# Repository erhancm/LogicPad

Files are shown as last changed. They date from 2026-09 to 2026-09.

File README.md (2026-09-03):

<p align="center">
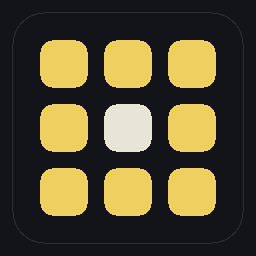
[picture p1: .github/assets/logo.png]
LogicPad
  
</p>

<h1 align="center">LogicPad</h1>

<p align="center">
  <strong>A programmable USB macro pad — and a desktop app that makes it yours.</strong><br>
  Assign macros, build lighting profiles, auto-switch layouts per app, back up your setups, and update firmware — all over USB.
</p>

<p align="center">
  
  
  
  
</p>

<p align="center">
  <a href="#-logicpad-configurator">Configurator</a> ·
  <a href="#-features">Features</a> ·
  <a href="#-hardware">Hardware</a> ·
  <a href="#-quick-start">Quick start</a> ·
  <a href="https://git.erhancm.com/erhan/LogicPad/releases">Download app</a>
</p>

---

## 💻 LogicPad configurator

LogicPad shows up as a standard USB keyboard when you plug it in, so it works without any software. The **Windows, macOS, and Linux** configurator app (built with Tauri 2) gives you a full-screen key editor, YAML profile packs, automatic profile switching based on which app you're using, and **firmware updates over USB**.

<table>
  <tr>
    <td colspan="2" align="center">
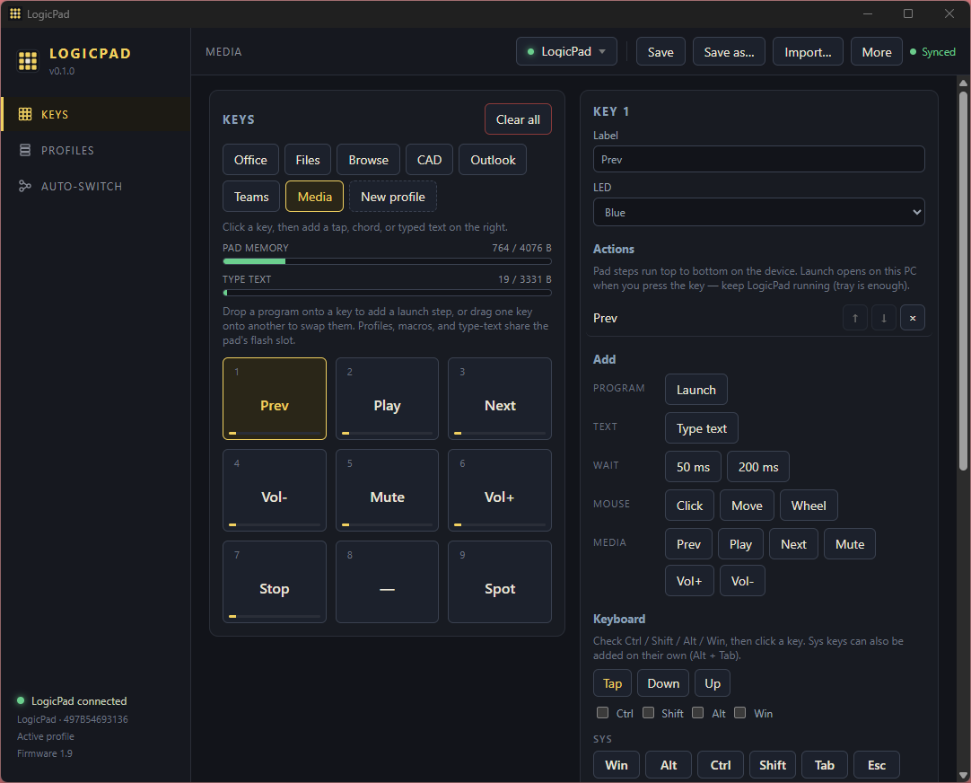
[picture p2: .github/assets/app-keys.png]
LogicPad configurator — Keys tab with 3×3 grid, macro steps, and typed text
      
      <br><sub><b>Keys</b> — macros, chords, typed text, and drag-and-drop PC program launch</sub>
    </td>
  </tr>
  <tr>
    <td width="50%" align="center">
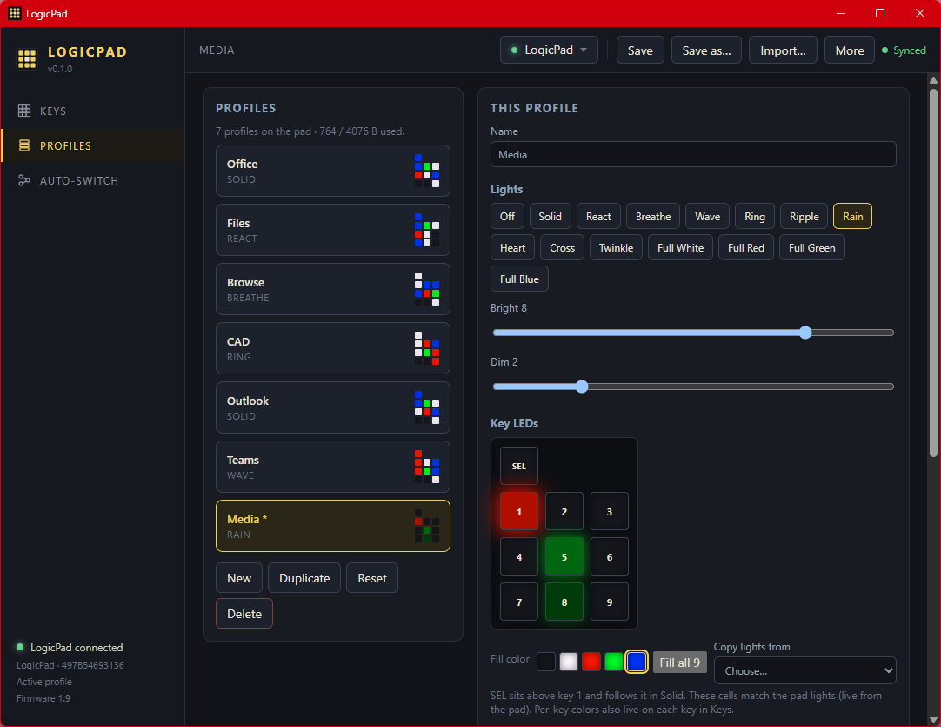
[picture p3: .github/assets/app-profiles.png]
LogicPad configurator — Profiles tab with lighting modes and per-key colours
      
      <br><sub><b>Profiles</b> — wave, ripple, breathe &amp; rain lighting · per-key colours · OLED settings</sub>
    </td>
    <td width="50%" align="center">
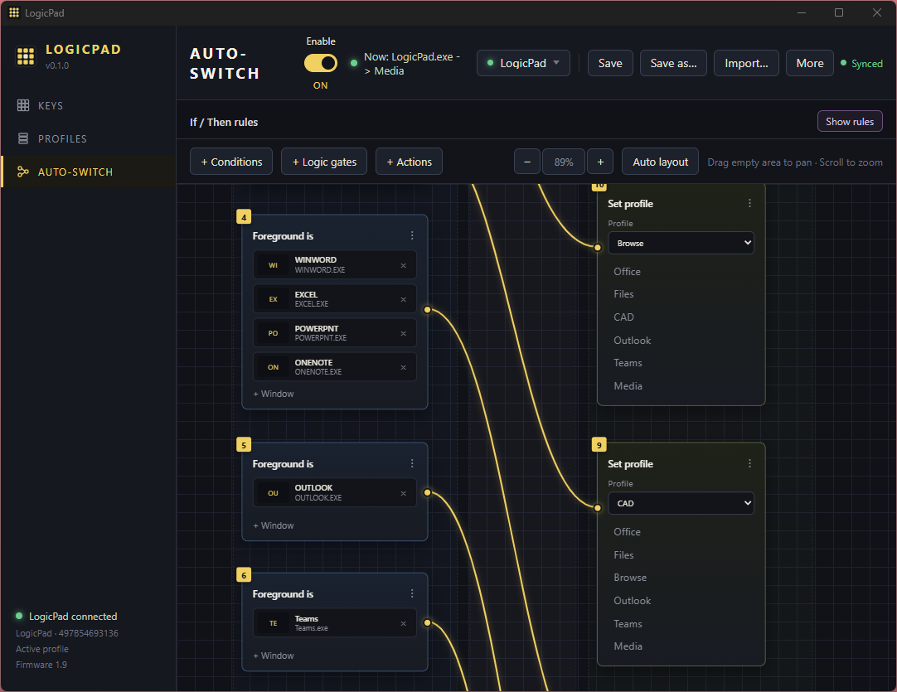
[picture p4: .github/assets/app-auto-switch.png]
LogicPad configurator — Auto-switch node graph
      
      <br><sub><b>Auto-switch</b> — switch profiles when you focus or run specific apps</sub>
    </td>
  </tr>
</table>

### Try it without hardware

The app has a built-in simulated LogicPad so you can try everything without owning the physical board. Note that the software is still a work in progress — some features aren't implemented yet.

### Install the app

Download from **[Releases](https://git.erhancm.com/erhan/LogicPad/releases)**:

| Platform | Download | Install |
|---|---|---|
| **Windows** | `LogicPad_*_x64-setup.exe` | Run the installer |
| **macOS** | `LogicPad_*_x64.dmg` | Open the DMG, drag LogicPad to Applications |
| **Linux** | `LogicPad_*_amd64.AppImage` | `chmod +x LogicPad_*.AppImage && ./LogicPad_*.AppImage` |
| **Linux** | `logicpad-app_*_amd64.deb` | `sudo apt install ./logicpad-app_*_amd64.deb` |
| **All** | `LogicPad-Productivity.yaml` | Import in the app (**Import…**) Example configuration |

**Linux note:** You'll need to install a [udev rule](04%20Software/logicpad-app/README.md#linux-udev) so the app has permission to communicate with the pad over USB. Without it, the app can't detect the device.

**Build from source:** `cd "04 Software/logicpad-app" && npm install && npm run build:app`

**Showcase demo:** [`04 Software/logicpad-app/showcase/`](04%20Software/logicpad-app/showcase/) comes with five pre-built profiles.

**Full app docs:** [`04 Software/logicpad-app/README.md`](04%20Software/logicpad-app/README.md)

---

## 🎯 Features

| | |
|---|---|
| **Keys** | A 3×3 grid of macro keys. Each key can trigger a keyboard shortcut, mouse click, media control or typed string (up to 240 bytes per key). You can also launch a PC program directly from a key. |
| **Profiles** | Create as many profiles as the internal flash allows. Each profile has its own lighting mode (wave, ripple, breathe, rain) or per-key RGB colours. |
| **Auto-switch** | A visual node graph lets you define rules like "when Spotify is focused, switch to the Media profile." Supports foreground-app and running-app checks, AND/OR logic gates.
| **YAML packs** | Export your entire setup — profiles, key mappings, and auto-switch rules — to a single YAML file. Import it later or share it with others. Use **Save as…** / **Import…** in the app. |
| **On-board bootloader** | Every board has a 4 KB USB HID bootloader. After the first flash, you can update firmware straight from the app — no ST-Link or disassembly needed. If something goes wrong, hold **SEL** while plugging in to enter recovery mode. |
| **On-device OLED editor** | Don't have the app? You can configure keys, profiles, and settings entirely from the pad's OLED screen using the selector and the nine keys as a d-pad. |
| **Plug-and-play HID** | LogicPad appears as a standard USB keyboard, mouse, and media device. No custom drivers needed on Windows, macOS, or Linux. |
| **Open hardware** | Full KiCad schematic and PCB layout. |

---

## 🔩 Hardware

<p align="center">
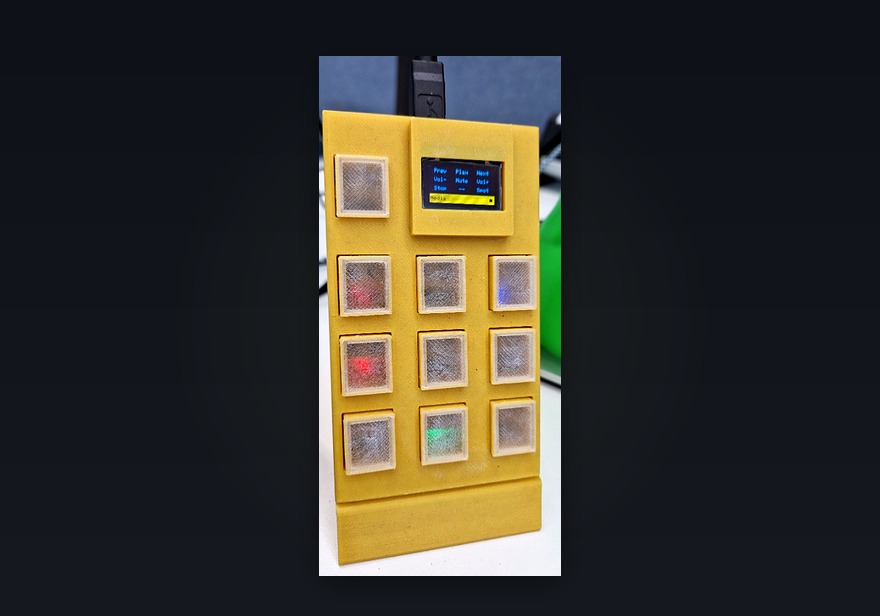
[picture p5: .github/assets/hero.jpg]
LogicPad macro pad — OLED showing Media profile, per-key RGB backlight
  
</p>

<p align="center">
  <em>9 macro keys + selector · 0.96″ OLED · per-key RGB · STM32F103 · 3D-printable enclosure</em>
</p>

| Spec | Detail |
|---|---|
| MCU | STM32F103C8 (ARM Cortex-M3) — 64 KB flash, 20 KB RAM |
| Keys | 9 macro keys + 1 selector button |
| Display | 0.96″ SSD1306 OLED, 128×64 pixels, connected over I²C |
| Lighting | Per-key RGB using 2020-size LEDs |
| USB | Composite HID device — keyboard + mouse + media controls + vendor-specific reports for app communication |
| Flash map | **4 KB** bootloader · **52 KB** application · **8 KB** persistent config store |

Current hardware revision: **V0.2** in [`02 Electronics/V0.2/`](02%20Electronics/V0.2/).

### Firmware updates

Every LogicPad board has a **4 KB USB HID bootloader** baked into flash. Once the board has been programmed for the first time, all future firmware updates happen over a regular USB cable — no ST-Link, no SWD debugger, and no need to open the enclosure.

**Updating firmware:**

1. Build the application firmware with the `Release` CMake preset in [`03 Firmware/Firmware/`](03%20Firmware/Firmware/).
2. Open the configurator app, click **Update firmware**, and select your `LogicPad.bin` file. The app communicates with the bootloader over USB HID and flashes the new image.

**Recovery:** If a firmware update fails or the app won't boot, hold the **SEL** button while plugging in the USB cable. This forces the board into bootloader mode so you can re-flash.

**First-time programming** still requires an ST-Link programmer (one-time only). The factory image `LogicPad_factory.hex` bundles both the bootloader and the application. See [`03 Firmware/bootloader/README.md`](03%20Firmware/bootloader/README.md) for details.

---

## 🚀 Quick start

### Daily use (no app needed)

1. **Plug in USB.** The host OS recognises LogicPad as a standard HID keyboard (plus mouse and media controls if you've configured them). No drivers, no pairing — it just works.

2. **Navigate the OLED menus.** A short press on the **selector** (SEL) button opens the on-device menu. Inside menus, the nine keys double as a d-pad for navigation:

   <table>
     <tr>
       <td width="55%">
         <table>
           <tr><th>Key</th><th>Action</th></tr>
           <tr><td>2</td><td>Up</td></tr>
           <tr><td>8</td><td>Down</td></tr>
           <tr><td>4</td><td>Left</td></tr>
           <tr><td>6</td><td>Right</td></tr>
           <tr><td>5</td><td>OK (select)</td></tr>
         </table>
         <p><strong>Short press SEL</strong> = go back one level. 
       </td>
       <td width="45%" align="center">
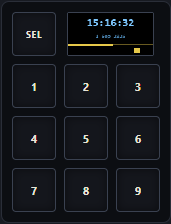
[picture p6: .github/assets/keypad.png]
LogicPad keypad layout
         
       </td>
     </tr>
   </table>

3. **Assign your macros.** Factory boards ship with empty key slots. You can assign macros either from the OLED menu (no PC required) or from the app. The app has more options.

### Build firmware from source

You'll need an ARM GCC toolchain and CMake. Both the bootloader and application firmware use CMake presets.

1. **Build the bootloader** — open [`03 Firmware/bootloader/`](03%20Firmware/bootloader/) and build with the `Release` CMake preset.
2. **Build the application** — open [`03 Firmware/Firmware/`](03%20Firmware/Firmware/) and build with the `Release` CMake preset.
3. **First-time flash** — combine bootloader + app into `LogicPad_factory.hex` and flash it via ST-Link (this is the only time you need ST-Link).
4. **All later updates** — just click **Update firmware** in the configurator app and point it at your new `LogicPad.bin`. The on-board bootloader handles the rest over USB.

---

## 📁 Repository layout

The repo is organised by discipline, numbered so it sorts in a logical order:

| Path | Contents |
|---|---|
| [`01 Documentation/`](01%20Documentation/) | Hardware and protocol docs — MCU pinout, HID report format, OLED menu structure, and C4 architecture diagrams. |
| [`02 Electronics/V0.2/`](02%20Electronics/V0.2/) | KiCad schematic and PCB layout for the current board revision, plus BOM and Gerber files for manufacturing. |
| [`03 Firmware/Firmware/`](03%20Firmware/Firmware/) | Production firmware for the STM32F103. CMake-based build with ARM GCC. Handles USB HID, key scanning, OLED display, RGB lighting, and config storage. |
| [`03 Firmware/bootloader/`](03%20Firmware/bootloader/) | On-board USB HID bootloader. Occupies the first 4 KB of flash and allows firmware updates over USB without a debugger. |
| [`04 Software/logicpad-app/`](04%20Software/logicpad-app/) | Desktop configurator app — Tauri 2 (Rust + web frontend). Handles key editing, profile management, auto-switch rules, YAML import/export, and firmware updates. |
| [`05 Hardware/`](05%20Hardware/) | 3D-printable enclosure — STEP files for the case and button caps. |
| [`.github/assets/`](.github/assets/) | Images used in this README. |

---

## 📖 Documentation

- [Pinout](01%20Documentation/Pinout.md) — MCU pin assignments, key matrix wiring, OLED connections, and RGB data lines
- [HID protocol](01%20Documentation/HID_PROTOCOL.md) — USB HID report format and vendor-specific commands used by the configurator app
- [OLED UI](01%20Documentation/OLED_UI.md) — on-device menu structure and navigation flow
- [C4 architecture](01%20Documentation/C4_MODEL.md) — high-level system overview in C4 model notation

---

## 🤝 Contributing

Contributions are welcome — whether it's a bug report, a feature request, or a pull request. If you're planning a larger change, it's worth opening an issue first to discuss the approach. By contributing, you agree that your contributions will be licensed under [Apache 2.0](LICENSE).

---

## 🐛 Known issues

| Issue | Type | Status | Notes |
|---|---|---|---|
| Sometimes you can't pan across the node editor when clicking on an empty area and dragging the mouse | Software | Open | Needs more investigation |
| OLED flicker or banding when taking pictures with camera| Software | Open | To do with refresh rate |
| Standby Clock setting is not persistant | Firmware | Open | When powering the unit off and on, the standby clock is reset to the default setting |
| Not all standby clock styles work | Software + Firmware | Open | Needs more investigation |
| LEDs can't reach full brightness in custom lighting modes | Hardware | Open | The LEDs are scanned one key at a time (1/9 duty cycle), so each LED is only actually on for a fraction of the time — the rest just looks lit because of persistence of vision. The STM32F103's GPIO pins can't source enough current to drive all 27 LEDs (9 keys × 3 colours) at once, so the per-LED brightness is capped by the scan rate. |

---

## 📝 To-do

| Feature | Type | Status | Notes |
|---|---|---|---|
| Custom scripting assignable to each button | Software | Planned | Python/Lua scripts — TBD |
| Mouse and keyboard recording | Software | Planned | Record input sequences and replay them from a key |
| OCR-based automation | Software | Planned | Use image recognition to perform actions based on what's on screen |
| Long press functions | Software + Firmware | Planned | Different actions for short vs. long key presses |
| Profile hotkeys | Firmware | Planned | Assign a key to cycle through or jump to specific profiles instead of going through the on-board menu (temporarily override auto-switch condition) |

### Hardware V0.3

| Feature | Status | Notes |
|---|---|---|
| Upgrade MCU to STM32F4 or RP2040 | Planned | More flash and RAM for larger configs, scripting support, and faster USB |
| USB-C connector | Planned | Replace the current Micro-USB with USB-C for better durability and reversibility |
| Hot-swap key sockets | Planned | Swap switches without soldering |
| Per-key addressable LEDs (WS2812B) | Planned | Remove the 1/9 scanning limitation and allow full brightness on all keys simultaneously |
| Larger OLED display | Planned | Upgrade from 0.96″ to 1.3″ for more readable menus and more info on screen |
| Rotary encoder | Planned | Add a clickable rotary encoder for volume control, scrolling, or menu navigation |
| Slider potentiometer | Planned | Linear slider for volume, brightness, or other continuous control |
| External flash storage | Planned | Dedicated flash chip or SD card slot — TBD. Would allow storing more profiles, macros, and recorded scripts on-device |
| Temperature and humidity sensor | Planned | Environmental sensor for ambient readings displayed on the OLED or used in automation rules. Including support for logging |

---

## 📄 License

This project is licensed under the [Apache License 2.0](LICENSE).

The third-party libraries bundled in `03 Firmware/Firmware/Drivers/` — namely the STM32 HAL, CMSIS, and ST's USB device library — are not covered by this license. They remain under their respective upstream licenses from STMicroelectronics and ARM.

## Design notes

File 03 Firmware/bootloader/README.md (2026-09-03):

# LogicPad HID bootloader

4 KB USB HID updater at `0x08000000`. The STM32F103C8 ROM loader has no USB DFU.

## Build

Needs `arm-none-eabi-gcc` on PATH (STM32CubeCLT is fine).

```
cd "03 Firmware/bootloader"
cmake --preset Release
cmake --build --preset Release
```

Produces `build/Release/bootloader.bin` (must be ≤ 4096 bytes).

Then build the app with CMake preset `Release` in `03 Firmware/Firmware/`. That writes `LogicPad.bin` (updater image) and, if the bootloader binary exists, `LogicPad_factory.hex` (first ST-Link flash).

## First flash (ST-Link, once)

Program `LogicPad_factory.hex`. After that, use the Tauri app **Update firmware** with `LogicPad.bin` only.

## Recovery

Hold SEL while plugging USB. Device enumerates as **LogicPad Boot** (VID `0x0483`, PID `0x5751`). OLED shows **BOOT** / **USB FLASH**.

In-app **Update firmware** resets into this loader (software-reset stay + SRAM magic). The OLED boot screens and that stay logic only update when you ST-Link `LogicPad_factory.hex`.

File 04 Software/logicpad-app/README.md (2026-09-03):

# LogicPad configurator

Optional Tauri 2 desktop app. The pad works as a USB HID keyboard without it.

Talks **vendor HID report 4** only (usage page `0xFF00`), so the host keeps reports 1–3 for typing. USB IDs: ST test VID/PID `1155` / `22352` (application) and `22353` (`0x5751`, bootloader) until custom IDs are assigned.

Licensed under [Apache 2.0](../LICENSE).

## Daily use (Windows)

**Install from a [Gitea Release](https://git.erhancm.com/erhan/LogicPad/releases)** — pick the installer for your OS (Windows `.exe`, macOS `.dmg`, Linux `.AppImage` or `.deb`), then start **LogicPad**.

Or build locally:

```
cd "04 Software/logicpad-app"
npm install
node generate-icons.mjs
npm run build:app
```

Or double-click `Build LogicPad.bat` in that folder. That installs to `%LOCALAPPDATA%\LogicPad\` (current user, no admin) and writes:

- `src-tauri/target/release/LogicPad.exe` — the raw program
- `src-tauri/target/release/bundle/nsis/LogicPad_0.1.0_x64-setup.exe` — installer

WebView2 is already on Windows 10/11. Rebuild the same way after app code changes.

## Develop

Needs Node 20+ and [Rust](https://rustup.rs/) (stable). On Windows, MSVC build tools. Cargo must be on `PATH` (`%USERPROFILE%\.cargo\bin`).

```
cd "04 Software/logicpad-app"
npm install
npm run tauri dev
```

Connect with a pad plugged in, or use the **Simulated LogicPad** to draft a setup on this PC. **Save as…** writes a YAML pack; **Import…** applies that file onto whichever pad is selected in **Pad**. One pad is selected automatically; two or more keep the last one you used. Edit the 3×3 keys and macros on **Keys**. **Profiles** is name, lighting, key LEDs, duplicate/reset, and OLED Screen (contrast / flip / sleep). **New** / **Duplicate** / **Delete** add or remove a profile (until the pad’s flash slot is full). **Save** writes flash on the device (or the local simulated store). **Update firmware** takes the app `LogicPad.bin` (not the factory hex) and programs the selected USB pad.

Drop an `.exe` or shortcut onto a key to launch it from this PC (stored locally, not on the pad). Key labels are 12 characters on current firmware (OLED wraps to two lines past 10). The **Type text** box is what the pad types over USB; a live bar shows pad flash (profiles + macros + text share one slot) and 240 B max per key. Flash firmware that includes `GET_TEXT` / `SET_TEXT` (`0x0F` / `0x10`) for strings longer than 12 characters, and `GET_TITLE` / `SET_TITLE` (`0x13` / `0x14`) for 12-character key names. Packed-store firmware uses magic `LPAI` and migrates `LPAH` config on boot.

**Launch program** on a key is stored on this PC (not on the pad). Pressing that key opens the file while this app is running. Flash firmware that includes `KEY_EVENT` (`0x0D`).

**Auto-switch** on the **Auto-switch** tab switches pad profiles when you focus an app. Use the compact rules list or open the **graph** editor for AND/OR, running checks, foreground/not-focused logic, and a default fallback (for example a Media profile when no rule matches). Rules are stored locally (`profile-rules.json`), not on the pad. Enable auto-switch in the app; it can start with Windows when launch mappings or rules exist. Firmware that does not mark the store dirty on `SET_ACTIVE` avoids an OLED save prompt on every Alt-Tab.

Home/sleep on the pad shows the **active profile** while you are using Windows. The clock comes back if USB drops, the session is locked, or you log off. That lock/logoff switch needs this tray app (and firmware with `SET_HOST` `0x15`).

## Linux udev

Not a custom driver. One rule so hidapi can open hidraw without root:

```
# /etc/udev/rules.d/99-logicpad.rules
KERNEL=="hidraw*", ATTRS{idVendor}=="0483", ATTRS{idProduct}=="5750", MODE="0666", TAG+="uaccess"
KERNEL=="hidraw*", ATTRS{idVendor}=="0483", ATTRS{idProduct}=="5751", MODE="0666", TAG+="uaccess"
```

Then `sudo udevadm control --reload-rules && sudo udevadm trigger`.

## Protocol

See [`01 Documentation/HID_PROTOCOL.md`](../../01%20Documentation/HID_PROTOCOL.md). Key payloads are the first 60 bytes of `lp_key_t` (up to 12 actions).

## Releases

Publish with [`scripts/Publish-Gitea-Release.ps1`](../../scripts/Publish-Gitea-Release.ps1) (Windows only) or push a **`v*`** tag to trigger the cross-platform [`.gitea/workflows/release.yml`](../../.gitea/workflows/release.yml).

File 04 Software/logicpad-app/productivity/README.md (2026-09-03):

# Productivity profile pack

Example YAML setup: **Office**, **Files**, **Browse**, **CAD**, **Outlook**, **Teams**, and a **Media** fallback when no productivity app is focused.

## Apply to a connected pad

From PowerShell (LogicPad installed):

```powershell
& "04 Software\logicpad-app\productivity\Apply-Productivity.ps1"
```

LogicPad restarts, queues the setup, writes to USB flash when the pad connects, and opens the **Auto-switch** tab.

## Import manually

**Import…** in the companion app with `LogicPad-Productivity.yaml`.

## Regenerate after editing sources

```powershell
cd "04 Software/logicpad-app"
npx tsx productivity/export-yaml.ts
```

Profile and auto-switch definitions live in `src/productivity.ts` and `src/productivityGraph.ts`.

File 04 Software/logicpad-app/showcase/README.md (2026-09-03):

# LogicPad Showcase Demo

Advertising-ready configuration: **five profiles**, rich macros, PC program launches, and a **complex auto-switch graph** (multi-app OR, AND + running, running-only, else-restore).

## Apply to your connected pad

From PowerShell:

```powershell
& "04 Software\logicpad-app\showcase\Apply-Showcase.ps1"
```

LogicPad restarts, detects the flag, writes the demo to USB flash, and opens the **Auto-switch** tab.

## Profiles

| Profile | Lights | Highlights |
|---|---|---|
| **Create** | Wave / blue keys | Copy, paste, save, typed snippet, launch Cursor |
| **Stream** | Ripple / red | OBS scene hotkeys, media volume, mouse click, launch OBS |
| **Meet** | Solid / green | Mute, camera, share, leave, launch Teams |
| **Browse** | Breathe / white | Tabs, back/forward, reload, typed URL |
| **Play** | Rain / blue | Media transport, multi-step macro |

## Auto-switch graph

1. **Create** — foreground `Cursor.exe`, `Code.exe`, or `Figma.exe`
2. **Stream** — foreground `obs64.exe` **and** `Discord.exe` running
3. **Meet** — foreground `Teams.exe` or `Zoom.exe`
4. **Browse** — foreground Chrome, Edge, or Firefox
5. **Play** — `Spotify.exe` running anywhere
6. **Else** — restore previous profile

## Share as YAML

Import `LogicPad-Showcase.yaml` via **Import…** in LogicPad (includes full auto-switch graph).

Regenerate after editing `src/showcase.ts`:

```powershell
cd "04 Software\logicpad-app"
npx tsx showcase/export-yaml.ts
```

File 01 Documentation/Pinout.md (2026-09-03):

# LogicPad Pinout

This is the definitive pin-mapping reference for the LogicPad hardware. Firmware must match this document.

**MCU:** STM32F103C8 (48-pin LQFP, 72 MHz, USB FS)
**USB:** Type-B connector, using the STM32's built-in USB FS peripheral. Standard OS HID drivers — no custom kernel driver needed.
**OLED:** 0.96-inch SSD1306, 128 x 64 pixels, connected over I2C1.

---

## Key Matrix

The 3 x 3 key grid plus the selector button are scanned as a matrix. The MCU drives columns low one at a time and reads the rows to detect which key is pressed.

**Scanning method:** Column drive, row read. Columns sit idle-high; the firmware pulls one column low per scan step and reads the row pins. A pressed key shows as low on its row when its column is driven low.

| Net Name | MCU Pin | Direction | Notes |
|---|---|---|---|
| Column_0 | PB5 | Output | Idle high; driven low to scan |
| Column_1 | PB4 | Output | Available as GPIO because SWJ is set to NOJTAG mode |
| Column_2 | PB3 | Output | Available as GPIO because SWJ is set to NOJTAG mode |
| Row_0 | PB12 | Input, pull-up | Top row of the key grid |
| Row_1 | PB13 | Input, pull-up | Middle row |
| Row_2 | PB14 | Input, pull-up | Bottom row |
| Selector | PB15 | Input, pull-up | Standalone button below the grid. Short press = menu/back, long press (500 ms) = home. Not a 10th macro key. |

### Key Index Map

Keys are indexed in row-major order (left to right, top to bottom):

```
[0] [1] [2]      row 0
[3] [4] [5]      row 1
[6] [7] [8]      row 2
      [SEL]       selector button (below the grid, centered)
```

> **Note:** Older test firmware used the opposite scanning direction (row drive, column read). Do not use that polarity — the current production firmware uses column drive / row read as described above.

---

## OLED Display (I2C1)

The SSD1306 OLED communicates over I2C1 at 400 kHz (fast mode).

| Net Name | MCU Pin  | I2C Function |
|---|---|---|
| SCL | PB6 | I2C1 clock |
| SDA | PB7 | I2C1 data |

**I2C address:** `0x78` (8-bit HAL address, which is `0x3C` in 7-bit notation).

---

## Per-Key RGB LEDs

Each of the 9 keys and the selector button has its own RGB LED. The LEDs are driven by a software PWM multiplexer running on TIM2 at 16 kHz (about 111 Hz refresh per key with 16 PWM steps).

### Anode (High-Side) Switches — PA0 through PA8

Each key's LED anode is switched through a **BSS84 P-channel MOSFET**. The GPIO pins on PA0 through PA8 control these switches:

| Net Name | MCU Pin | Key Index | Notes |
|---|---|---|---|
| C0R0 | PA0 | 0 | Top-left key |
| C0R1 | PA1 | 1 | Top-center key |
| C0R2 | PA2 | 2 | Top-right key |
| C1R0 | PA3 | 3 | Middle-left key |
| C1R1 | PA4 | 4 | Middle-center key |
| C1R2 | PA5 | 5 | Middle-right key |
| C2R0 | PA6 | 6 | Bottom-left key |
| C2R1 | PA7 | 7 | Bottom-center key |
| C2R2 | PA8 | 8 | Bottom-right key |
| CtrlLed  | PA9 | SEL | Selector RGB LED (10th pixel, not a 10th macro key) |

**Polarity:** GPIO **low = LED on**, GPIO **high = LED off** (P-FET high-side switch).

> **Important:** The net names (C0R0, C0R1, C0R2, ...) walk down each column on the MCU port, which is the transpose of the physical key grid. The firmware accounts for this — key index 0 maps to C0R0 (PA0), key index 1 maps to C0R1 (PA1), and so on in row-major order.

### Color Sink (Low-Side) Switches — PB8, PB9, PB10

The red, green, and blue color channels share common sink lines. Each channel is switched through a **2N7002 N-channel MOSFET**:

| Net Name | MCU Pin | Color  | Polarity |
|---|---|---|---|
| R_Ctrl | PB8 | Red | GPIO **high = on**, low = off |
| G_Ctrl | PB9 | Green  | GPIO **high = on**, low = off |
| B_Ctrl | PB10 | Blue | GPIO **high = on**, low = off |

White is achieved by turning on all three color channels simultaneously.

---

## USB

The LogicPad connects to the host via a **USB Type-B** connector wired to the STM32F103's built-in USB FS peripheral. It presents as a standard HID composite device (keyboard, mouse, media keys, and vendor-specific reports). The host OS uses its inbox HID drivers — no custom kernel driver is required.

---

## Pin Usage Summary

| Port | Pins Used | Function |
|---|---|---|
| PA0  | PA0 - PA8 | LED anode switches (9 keys) |
| PA9  | PA9 | Selector LED anode switch |
| PA11 | PA12 | USB D- / D+ (USB FS peripheral) |
| PB3  | PB3 - PB5 | Key matrix columns (outputs) |
| PB6  | PB7 | I2C1 SCL / SDA (OLED) |
| PB8  | PB8 - PB10  | LED color sinks (R, G, B) |
| PB12 | PB12 - PB14 | Key matrix rows (inputs, pull-up) |
| PB15 | PB15 | Selector button (input, pull-up) |

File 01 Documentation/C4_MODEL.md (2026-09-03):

# LogicPad C4 Model

This document describes the LogicPad system using the [C4 model](https://c4model.com/) — four levels of increasing detail, from the big picture down to individual data structures.

LogicPad is a USB HID macro pad. It presents itself as a standard keyboard, mouse, and media device — **there is no custom kernel driver**. The host OS handles reports 1–3 with its inbox HID stack. Report 4 (vendor) is opened in userspace by the optional desktop app via hidapi.

**Source files:** `README.md`, `HID_PROTOCOL.md`, `Pinout.md`, `OLED_UI.md`, `03 Firmware/`, `04 Software/logicpad-app/`.

| Level | What it shows |
|---|---|
| 1 — Context | People and external systems around LogicPad |
| 2 — Containers | Deployable units: firmware images, OS HID drivers, the Tauri app, config files |
| 3 — Components | Modules inside each container: firmware C modules, Rust backend, React UI, USB stack |
| 4 — Code | Flash memory map, HID report layout, vendor command table |

---

## Level 1 — System Context

The macro pad works as a standalone USB HID device — just plug it in and type. The OLED screen and physical keys let the operator configure macros directly on the device. The desktop configurator app is entirely optional; it provides a richer editing experience, profile management, firmware updates, and automatic profile switching based on the focused application.

Factory programming (first flash or brick recovery) uses an ST-Link debugger over SWD. After that, all firmware updates go through the built-in HID bootloader — no special tools needed.

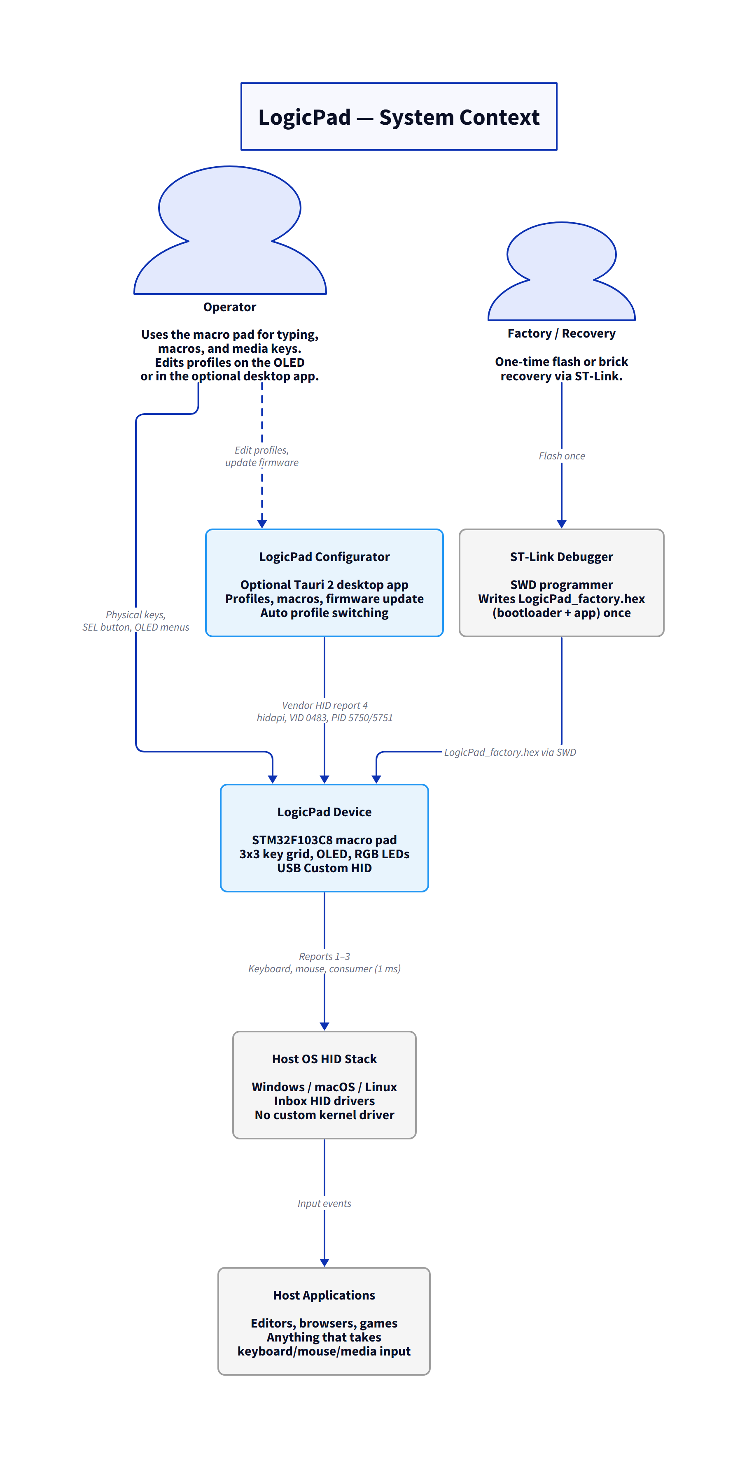
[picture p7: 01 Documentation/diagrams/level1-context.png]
Level 1 — System Context


---

## Level 2 — Containers

The device exposes a single USB Custom HID interface. The OS automatically claims reports 1–3 (keyboard, mouse, consumer) through its standard class drivers. The desktop app opens only the vendor collection (usage page `0xFF00`), so normal typing continues uninterrupted while the app is connected.

On the host side, the Tauri app bundles a React frontend with a Rust backend. The Rust side owns the hidapi connection and handles all USB communication. The app stores host-side configuration (launch mappings and profile switch rules) in JSON files — these live on the PC, not in the pad's flash.

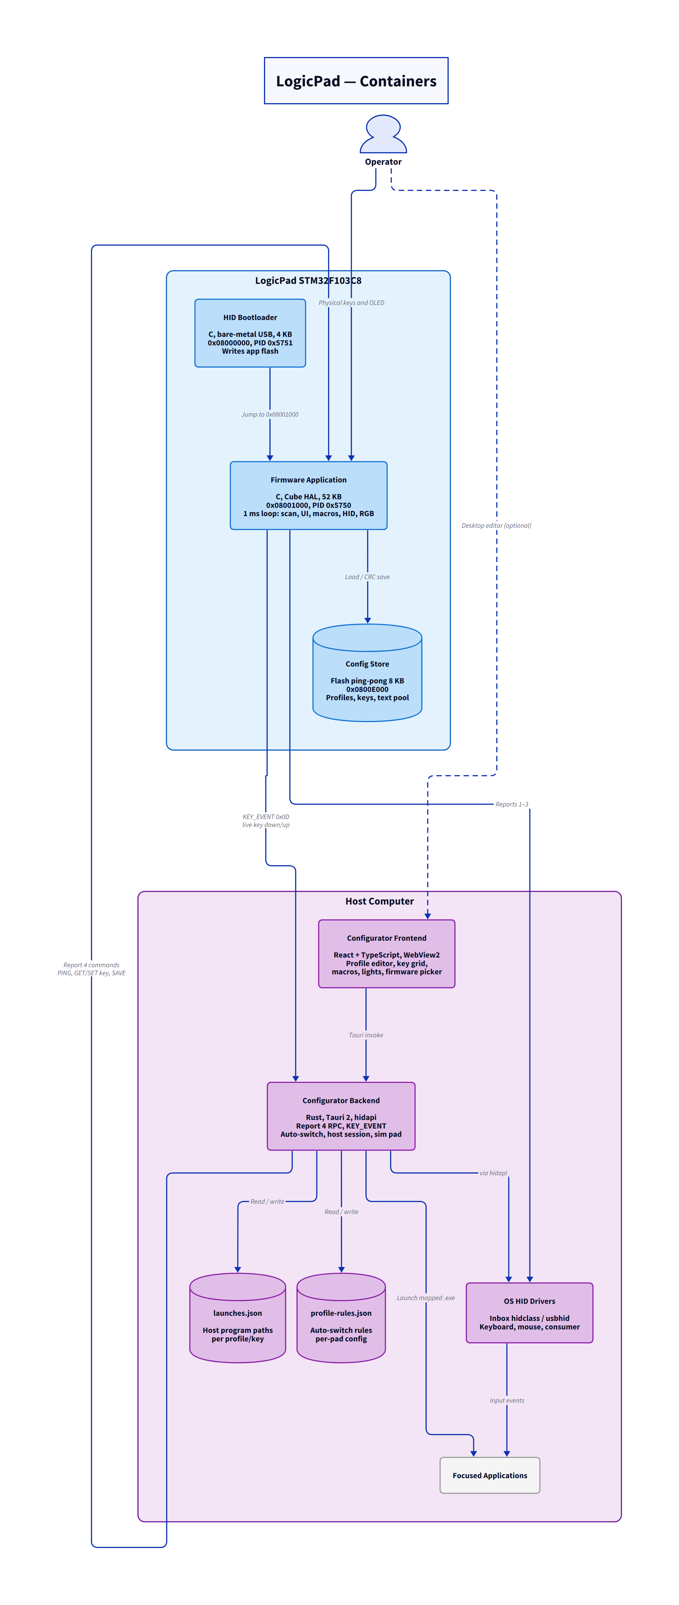
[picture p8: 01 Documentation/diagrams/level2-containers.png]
Level 2 — Containers


**Linux note:** hidapi needs access to `/dev/hidraw`. The udev rule in the app README grants this permission — it is not a driver.

---

## Level 3 — Firmware Application

The firmware runs a catch-up tick loop in `main.c`. Each iteration processes all elapsed milliseconds since the last pass, calling `ui_tick()` for each one (which includes keypad scanning). After the tick loop, `hid_tick()` and `macro_tick()` run once. OLED drawing is deferred to when the macro engine is idle, since the I2C transfer to the SSD1306 display takes ~25 ms and would otherwise stall HID reporting.

USB IN/OUT is interrupt-driven through ST's device library. The bootloader has its own separate bare-metal USB stack (`bootloader/usb.c`) and is not shown here.

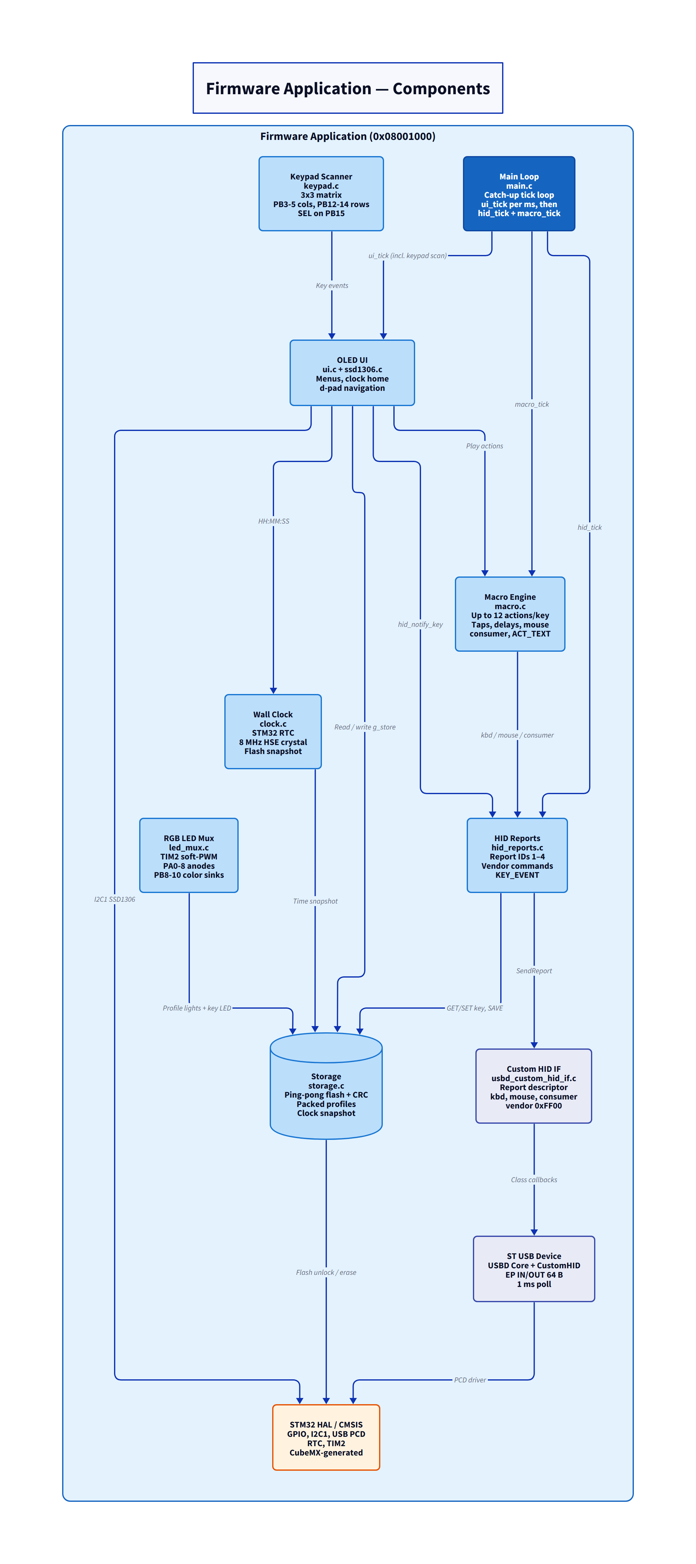
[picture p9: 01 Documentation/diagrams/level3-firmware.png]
Level 3 — Firmware Application


**Related docs:** [Pinout.md](Pinout.md) for hardware pins, [OLED_UI.md](OLED_UI.md) for screen layouts.

---

## Level 3 — Desktop Configurator

The desktop app is a Tauri 2 application with a React frontend and a Rust backend. The frontend never opens HID directly — all USB communication goes through the Rust side, which owns the hidapi connection on a dedicated worker thread.

The backend has grown beyond simple pad editing. It now handles automatic profile switching based on the focused Windows application, host session detection (lock/unlock), live window previews, and an in-memory simulated pad for testing without hardware.

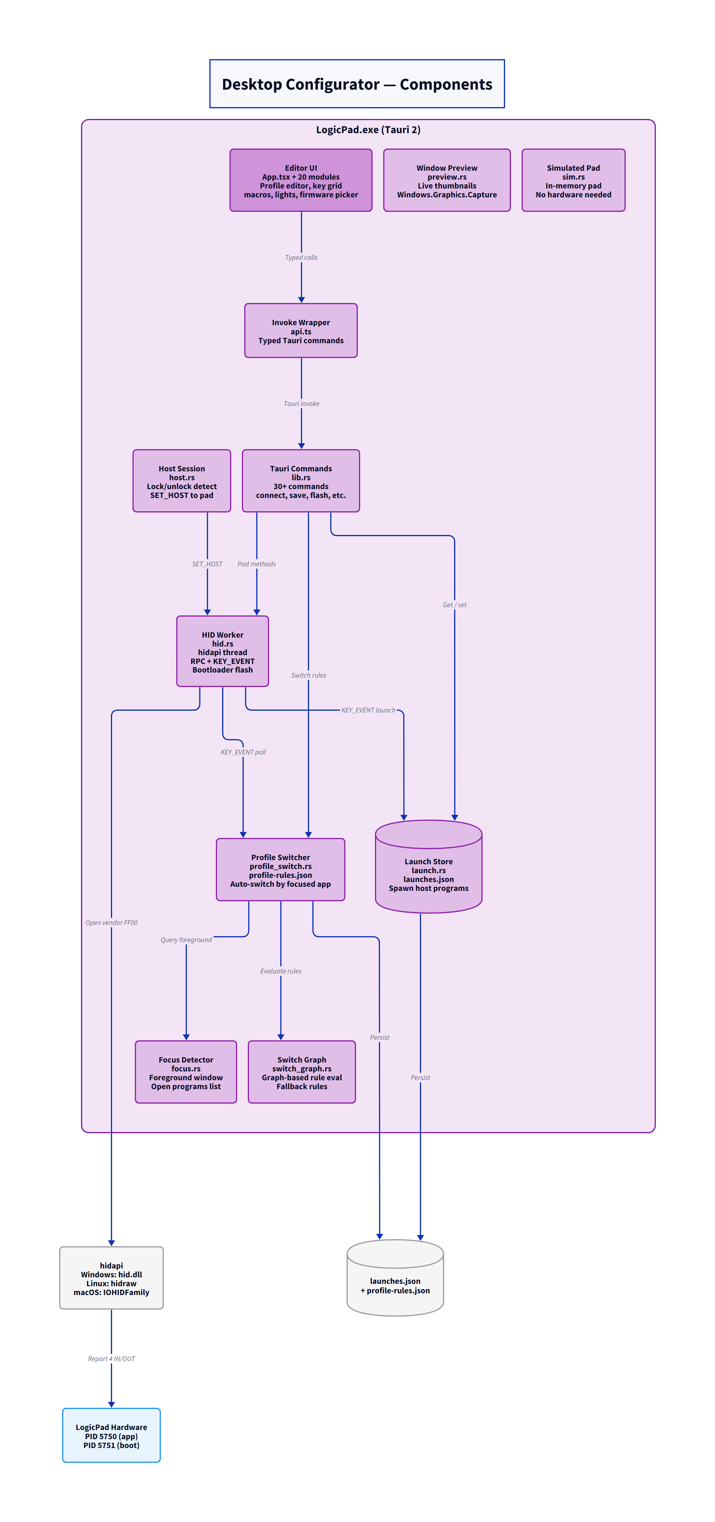
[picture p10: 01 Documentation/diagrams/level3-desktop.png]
Level 3 — Desktop Configurator


---

## Level 3 — USB / HID Stack (No Custom Driver)

This diagram shows the USB path as a stack of layers, from the application protocol down to the wire and back up on the host side. The bootloader does **not** use the ST USB library — it drives the same USB FS peripheral directly in `bootloader/usb.c`.

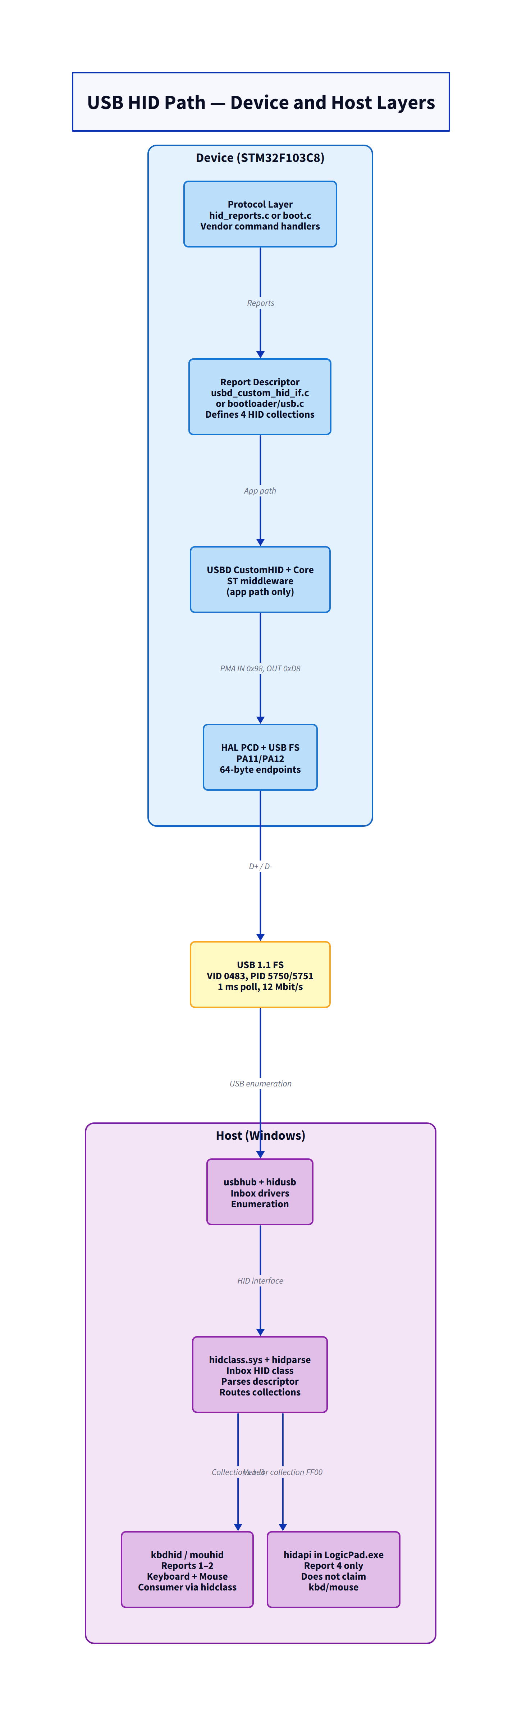
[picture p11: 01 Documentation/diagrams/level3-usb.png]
Level 3 — USB HID Stack


| Host OS | Reports 1–3 (keyboard/mouse/consumer) | Report 4 (vendor) |
|---|---|---|
| Windows | hidclass.sys + kbdhid/mouhid | hidapi via hid.dll (skips usage pages 0x01, 0x02, 0x0C) |
| macOS | IOHIDFamily | hidapi via IOHIDManager |
| Linux | usbhid + evdev | hidraw; requires udev rule `99-logicpad.rules` for unprivileged access |

---

## Level 4 — Code: Flash Map and HID Reports

**Chip:** STM32F103C8 — 64 KB flash, 20 KB SRAM. The built-in ROM bootloader only supports USART, so field firmware updates use the 4 KB HID bootloader instead.

### Flash Memory Map

| Region | Address | Size | Contents |
|---|---|---|---|
| HID Bootloader | `0x08000000` | 4 KB | Included in `LogicPad_factory.hex` only. Bare-metal USB stack. |
| Application | `0x08001000` | 52 KB | `LogicPad.bin` (also bundled in factory hex). Main firmware. |
| Config Store | `0x0800E000` | 8 KB | Ping-pong slots with CRC. Packed profiles, keys, text pool, clock snapshot. |
| SRAM Magic | `0x20004FFC` | 4 bytes | Write `LPBL` here before reset to stay in bootloader (used by ENTER_BOOTLOADER). |

### HID Reports

| Report ID | Size (bytes) | Direction | Handled By | Purpose |
|---|---|---|---|---|
| 1 | 9 | IN | OS | Keyboard: modifier byte + 6-key rollover |
| 2 | 5 | IN | OS | Mouse: buttons, X, Y, wheel |
| 3 | 3 | IN | OS | Consumer control: 16-bit usage (volume, media, etc.) |
| 4 | 64 | IN/OUT | App / Bootloader | Vendor commands (see HID_PROTOCOL.md) |

### Vendor Commands (Application)

The full command table is documented in `HID_PROTOCOL.md`. Key commands include:

| Cmd | Name | Description |
|-----|---|---|
| 0x01 | PING | Returns protocol version (major, minor) |
| 0x02 | GET_META | Active profile, dirty flag, OLED settings, store usage |
| 0x03 | GET_KEY | Read key config (label, LED, actions) for a profile/key |
| 0x04 | SET_KEY | Write key config |
| 0x05 | SET_ACTIVE | Switch live profile (does not mark flash dirty) |
| 0x06 | SAVE | Persist current config to flash with CRC |
| 0x0C | ENTER_BOOTLOADER | Ack, show OLED message, reset into HID bootloader |
| 0x0D | KEY_EVENT | Unsolicited: live key down/up notification |
| 0x0E | SET_TIME | Sync wall clock from host |
| 0x0F–0x10 | GET/SET_TEXT | Type-text pool read/write (chunked) |
| 0x11–0x12 | ADD/DEL_PROFILE | Add or delete profiles (up to 255) |
| 0x13–0x14 | GET/SET_TITLE | 12-character display title per key |
| 0x15 | SET_HOST | Notify pad of host session state (locked/unlocked) |
| 0x16 | SET_SCREEN | OLED contrast, flip, sleep timeout, clock style |
| 0x17 | GET_LEDS | Live RGB snapshot for app-side LED preview |
| 0x18 | PREVIEW_CLOCK | Show/hide clock preview on OLED |

**Bootloader commands:** `0x40` BL_START, `0x41` BL_DATA, `0x42` BL_FINISH, `0x43` BL_ABORT.

### Store Schema

Defined in `03 Firmware/Firmware/Core/Inc/storage.h`. The current packed format uses magic `LPAI` (`0x4C504149`). The bootloader migrates legacy `LPAH` (`0x4C504148`, fixed 4-profile) stores into the packed layout on first boot. Up to 255 profiles, 9 keys per profile, 12 actions per key, 240 bytes of type-text per key.

---

## Runtime Paths

These trace common operations through the code, showing which components are involved at each step.

### Typing a key (standalone, no desktop app)

1. `main.c` tick loop calls `ui_tick()`
2. `keypad.c` scans the 3x3 matrix, detects a key press (with debounce)
3. `ui.c` receives the event, looks up the active profile's key config
4. `macro.c` plays the key's action sequence (HID taps, delays, mouse moves, consumer keys, typed text)
5. `hid_reports.c` sends reports 1–3 via `usbd_custom_hid_if.c` → ST USB library → USB FS peripheral
6. Host OS HID stack delivers input to the focused application

### Typing a key (desktop app running, with launch mapping)

Same HID path as above (reports 1–3 still go to the OS), **plus:**

1. `hid_reports.c` sends an unsolicited `KEY_EVENT` (0x0D) over report 4
2. `hid.rs` worker thread receives it, dispatches to the registered callback
3. `launch.rs` checks if this profile/key has a mapped host program — if so, spawns it
4. `profile_switch.rs` also receives the event and can trigger auto-switch logic

### Auto profile switching (desktop app)

1. `profile_switch.rs` polls the focused Windows application via `focus.rs`
2. `switch_graph.rs` evaluates the rule graph against the focused program's executable name
3. If a rule matches and the profile differs from the current one, sends `SET_ACTIVE` to the pad
4. Debounce timer (400 ms) prevents rapid switching during alt-tab

### Host session detection (desktop app)

1. `host.rs` monitors Windows session events (lock, unlock, fast-user-switch, logoff)
2. When the session state changes, sends `SET_HOST` (0x15) to the pad
3. The pad uses this to decide whether to show the clock or profile name on the home screen, and when to enter sleep

### Saving from the desktop app

1. React UI calls `save_store` via the invoke wrapper
2. `lib.rs` forwards to `hid.rs` which sends `CMD_SAVE` (0x06) over report 4
3. `storage.c` on the pad writes the current config to flash with a CRC checksum

### Firmware update

1. Desktop app sends `ENTER_BOOTLOADER` (0x0C) — the pad acks, shows "FLASH / BOOT MODE" on the OLED, then resets
2. SRAM magic `LPBL` tells the bootloader to stay in update mode
3. Pad re-enumerates as PID `0x5751` (LogicPad Boot)
4. App sends `BL_START` (size + CRC), then `BL_DATA` chunks, then `BL_FINISH`
5. Bootloader verifies CRC and vector table, then jumps to `0x08001000`
6. **Recovery:** hold SEL while plugging in USB to force bootloader mode

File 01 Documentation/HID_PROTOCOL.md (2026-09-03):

# LogicPad HID Protocol

This document describes the USB HID protocol used by LogicPad — a macro pad that presents itself as a standard keyboard, mouse, and media device over a single Custom HID interface. The host OS handles reports 1–3 with its inbox class drivers; no custom kernel driver is needed. Report 4 (vendor) is ignored by the OS and opened in userspace by the optional Tauri desktop app via hidapi.

**Source files:** `03 Firmware/Firmware/Core/Inc/hid_reports.h`, `03 Firmware/Firmware/Core/Src/hid_reports.c`, `03 Firmware/Firmware/Core/Inc/storage.h`, `03 Firmware/bootloader/boot.c`, `04 Software/logicpad-app/src-tauri/src/hid.rs`.

---

## Report IDs

| ID | Size (incl. ID) | Direction | Purpose |
|----|---|---|---|
| 1 | 9 | IN | Keyboard: modifier byte, reserved, 6-key rollover |
| 2 | 5 | IN | Mouse: buttons, X, Y, wheel |
| 3 | 3 | IN | Consumer control: 16-bit usage (volume, media, etc.) |
| 4 | 64 | IN/OUT | Vendor commands — 63-byte payload (see below) |

Endpoint IN/OUT max packet size is 64 bytes. Poll interval is 1 ms.

---

## Vendor Packet Format

Every vendor packet is 64 bytes on the wire:

| Byte | Content |
|---|---|
| 0 | Report ID (`4`) |
| 1 | Command code |
| 2–63 | Payload (command-specific) |

The pad echoes the command byte in every reply.

### Protocol Versioning

`PING` returns a two-byte version: major `0x01`, then a minor number. The minor version tracks which features the firmware supports. The Tauri app uses this to enable or hide UI elements:

| Minor | Feature added |
|---|---|
| 0 | Base protocol (no type-text pool) |
| 1 | Type-text pool (`GET_TEXT` / `SET_TEXT`) |
| 2 | Add / delete profiles (`ADD_PROFILE` / `DEL_PROFILE`) |
| 3 | 12-character key titles (`GET_TITLE` / `SET_TITLE`) |
| 4 | Host session state (`SET_HOST`) |
| 5 | Packed flash store — profiles fill flash instead of a fixed 4-slot layout |
| 6 | OLED screen settings (`SET_SCREEN` — contrast, flip, sleep) |
| 7 | Live LED snapshot (`GET_LEDS`) |
| 8 | Standby clock style in `GET_META` / `SET_SCREEN` (`clock_style` field) |
| 9 | Clock preview (`PREVIEW_CLOCK`) |

Current firmware returns `0x01, 0x09`.

---

## Application Vendor Commands

| Cmd | Name | Host → pad | Pad → host |
|-----|---|---|---|
| 0x01 | PING | — | major `0x01`, minor (see versioning table) |
| 0x02 | GET_META | — | active, dirty, contrast, flip, sleep, in_menu, usb, n_profiles, used u16le, cap u16le, clock_style (minor ≥ 8) |
| 0x03 | GET_KEY | profile, key | profile, key, first 57 bytes of `lp_key_t` (`LP_KEY_HID_BYTES`) |
| 0x04 | SET_KEY | profile, key, 57-byte key blob | echo profile, key, status |
| 0x05 | SET_ACTIVE | profile | echo profile (live slot only; does not mark flash dirty) |
| 0x06 | SAVE | — | ack |
| 0x07 | RELOAD | — | ack |
| 0x08 | FACTORY | — | ack |
| 0x09 | GET_PROFILE_HDR | profile | index, name (13 bytes NUL-padded), light_mode, bright, dim |
| 0x0A | SET_PROFILE_HDR | index, name (13), light_mode, bright, dim | echo (17 bytes) |
| 0x0B | GET_STATUS | — | same as `GET_META` |
| 0x0C | ENTER_BOOTLOADER | — | ack, then reset into the 4 KB HID updater |
| 0x0D | KEY_EVENT | — | unsolicited IN: profile, key, down (1/0). Live keys only. |
| 0x0E | SET_TIME | year u16le, month, day, hour, min, sec (local 24h) | echo (7 bytes) |
| 0x0F | GET_TEXT | profile, key, offset | profile, key, total_len, offset, pool_used u16le, data (56 bytes) |
| 0x10 | SET_TEXT | profile, key, offset, total_len, data (58 bytes) | profile, key, offset, status, pool_used u16le |
| 0x11 | ADD_PROFILE | — | index, n_profiles, status |
| 0x12 | DEL_PROFILE | profile | profile, n_profiles, active, status |
| 0x13 | GET_TITLE | profile, key | profile, key, title (12 chars + NUL) |
| 0x14 | SET_TITLE | profile, key, title (12, NUL-padded) | echo profile, key |
| 0x15 | SET_HOST | `1` = PC session in use, `0` = away (locked / logged off) | echo |
| 0x16 | SET_SCREEN | contrast (0–10), flip (0–1), sleep (0–4), clock_style | echo + status byte (`0` ok, `1` bad values) |
| 0x17 | GET_LEDS | — | 10 colors, 10 duties, anim_ms u16le, idle_ms u16le, flash_key, flash_ms u16le, ripple_key, ripple_age u16le, flood (31 bytes) |
| 0x18 | PREVIEW_CLOCK | on (0/1) | echo on |

---

## Command Details

### PING (0x01)

Returns the protocol version. The app uses the minor number to decide which features are available (see versioning table above). No payload.

### GET_META (0x02) / GET_STATUS (0x0B)

Both return the same 13-byte response. `GET_STATUS` is an alias kept for compatibility.

| Offset | Size | Field | Description |
|---|---|---|---|
| 0 | 1 | active | Currently active profile index |
| 1 | 1 | dirty | `1` if config has unsaved changes |
| 2 | 1 | contrast | OLED contrast (0–10) |
| 3 | 1 | flip | OLED 180° flip (0/1) |
| 4 | 1 | sleep | Idle sleep timeout (0=Never, 1=15s, 2=30s, 3=1m, 4=5m) |
| 5 | 1 | in_menu | `1` if the OLED is showing a config menu; `0` on home screen, toast, or sleep |
| 6 | 1 | usb | `1` if USB is configured (host connected) |
| 7 | 1 | n_profiles | Number of stored profiles |
| 8–9 | 2 | store_used | Bytes used in the packed flash store (u16le) |
| 10–11 | 2 | store_cap | Total capacity of the packed flash store (u16le) |
| 12 | 1 | clock_style | Packed standby clock settings (minor ≥ 8; `0` on older firmware) |

### GET_KEY (0x03)

Reads a key configuration. Send `profile` (0-based) and `key` (0–8). The pad returns the profile and key indices followed by the first 57 bytes of `lp_key_t` — the HID prefix containing `label[7]`, `led`, action count `n`, and up to 12 `lp_action_t` entries (4 bytes each). The `title` field is not included; use `GET_TITLE` separately.

### SET_KEY (0x04)

Writes a key configuration. The 57-byte HID blob has the same layout as the `GET_KEY` response (label, LED, action count, actions). The pad preserves the existing `title` — `SET_KEY` does not touch it. Use `SET_TITLE` to update the 12-character display name separately.

**Status:** `0` = ok, `1` = flash slot full (change discarded).

### SET_ACTIVE (0x05)

Switches the live profile and redraws lights and OLED. Does **not** set the `dirty` flag, so the host auto-switch in the Tauri app will not trigger the OLED save prompt. Persist the change with **Save**, or change it on the device (OLED edits still mark dirty).

### SAVE (0x06)

Persists the current in-memory config to flash with a CRC checksum. The pad acks after the write completes.

### RELOAD (0x07)

Discards in-memory changes and reloads the config from flash. The pad acks and redraws.

### FACTORY (0x08)

Resets all profiles and settings to factory defaults, then saves to flash. The pad acks and redraws.

### GET_PROFILE_HDR (0x09)

Reads a profile's header. Send the profile index. Returns 17 bytes: index, name (13 bytes, NUL-padded), `light_mode`, `bright`, `dim`.

### SET_PROFILE_HDR (0x0A)

Writes a profile's header (name and lighting). Send 17 bytes matching the `GET_PROFILE_HDR` layout. Marks flash dirty.

### ENTER_BOOTLOADER (0x0C)

The pad acks immediately, then the main loop shows **FLASH / BOOT MODE** on the OLED and performs a system reset. The ack is sent from the USB callback — the actual reset happens in `hid_tick()`, not in the interrupt context, because USB IRQ priority 0 would hang `HAL_Delay`.

### KEY_EVENT (0x0D)

Unsolicited IN report. The pad sends this whenever a physical key is pressed or released while USB is configured. Payload: profile index, key index, down (`1` = pressed, `0` = released). Queued up to 4 events; oldest is dropped if the queue overflows. The Tauri app uses this for launch mapping and auto profile switching.

### SET_TIME (0x0E)

Syncs the pad's wall clock from the host. Payload: year (u16le), month, day, hour, minute, second — all in local 24-hour time. The pad keeps time on its own STM32 RTC (driven by the 8 MHz HSE crystal) for as long as it has USB power. There is no 32 kHz backup crystal or battery, so a full unplug loses the time; a flash snapshot restores the last saved clock. Until the first sync, the display starts at 16 Aug 2026 00:00:00.

### GET_TEXT (0x0F)

Reads a chunk of a key's type-text string. Send profile, key, and byte offset. Returns profile, key, total length, offset, pool_used (u16le), and up to 56 bytes of text data. Call repeatedly with increasing offsets to read the full string.

### SET_TEXT (0x10)

Writes a chunk of a key's type-text string. Send profile, key, byte offset, total length, and up to 58 bytes of data. The first packet (offset `0`) starts a new write; subsequent packets must continue from the next byte. An empty `total_len` clears that key's text.

**Status:** `0` = ok, `1` = flash slot full, `2` = text longer than 240 bytes, `3` = bad arguments (mismatched profile/key/offset/total).

### ADD_PROFILE (0x11)

Appends an empty profile with a default name (`P1`, `P2`, …) and Solid lighting. Returns the new index, updated `n_profiles`, and status.

**Status:** `0` = ok, `1` = slot full or already 255 profiles.

### DEL_PROFILE (0x12)

Compact-deletes the given profile slot. Returns the original index, updated `n_profiles`, current `active`, and status.

**Status:** `0` = ok, `2` = would leave zero profiles, `3` = bad index.

### GET_TITLE (0x13)

Reads the 12-character display title for a key. Send profile and key. Returns profile, key, and the title string (12 chars + NUL).

### SET_TITLE (0x14)

Writes the 12-character display title for a key. The pad also fills `label` with the first 6 non-space characters as a stub for old packets. OLED and the PC app show `title` (falling back to `label` if `title` is empty). Marks flash dirty.

### SET_HOST (0x15)

Notifies the pad of the host session state. Send `1` when the PC session is in use (unlocked), `0` when away (locked, logged off, or fast-user-switched). The pad uses this to decide whether to show the clock or profile name on the home screen, and when to enter sleep. USB unconfigured/suspend counts as away without the app.

### SET_SCREEN (0x16)

Writes pad-wide OLED settings. All values are applied to hardware immediately and mark flash dirty; persist with **Save**.

| Offset | Size | Field | Range |
|---|---|---|---|
| 0 | 1 | contrast | 0–10 |
| 1 | 1 | flip | 0 = normal, 1 = 180° rotation |
| 2 | 1 | sleep | 0 = Never, 1 = 15s, 2 = 30s, 3 = 1m, 4 = 5m |
| 3 | 1 | clock_style | Packed byte (see below) |

**Status:** `0` = ok, `1` = one or more values out of range.

#### clock_style packing

The `clock_style` byte controls the standby clock band animation on the OLED. It uses a v2 packing format (bit 6 set):

| Bits | Field | Values |
|---|---|---|
| 0–3 | Animation | 0 = Bounce, 1 = Scan, 2 = March, 3 = Pulse, 4 = Wave, 5 = Blocks, 6 = Comet, 7 = Swing, 8 = Fill, 9 = Sparkle, 10 = Ripple, 11 = Rain, 12 = Off |
| 4–5 | Speed | 0 = Slow (32 ms), 1 = Normal (16 ms), 2 = Fast (8 ms), 3 = Rapid (4 ms) |
| 6 | Seconds bar | 0 = off, 1 = on (thin progress bar across the clock band) |
| 7 | Reserved | Must be 0 |

The default is `0x50` (Bounce, Normal speed, seconds bar on).

**v1 → v2 migration:** Older firmware used a different bit layout (3-bit anim, 2-bit speed, 1-bit bar, no bit 6). The firmware and app both detect v1 by checking bit 6 = 0 and repack into v2 format automatically.

### GET_LEDS (0x17)

Copies the LED mux's current frame so the companion app can phase-lock animations instead of running a separate timer. Returns 31 bytes:

| Offset | Size | Field |
|---|---|---|
| 0–9 | 10 | Color per LED (keys 0–8, then SEL at index 9). Values: `LED_OFF/WHITE/RED/GREEN/BLUE` |
| 10–19 | 10 | Duty per LED (0–16 PWM steps after gamma correction) |
| 20–21 | 2 | `anim_ms` — animation clock (u16le) |
| 22–23 | 2 | `idle_ms` — idle timer (u16le) |
| 24 | 1 | `flash_key` — key currently flashing (0xFF = none) |
| 25–26 | 2 | `flash_ms` — flash timer (u16le) |
| 27 | 1 | `ripple_key` — ripple origin key (0xFF = none) |
| 28–29 | 2 | `ripple_age` — ripple timer (u16le) |
| 30 | 1 | `flood` — flood fill state |

This command does not mark flash dirty and does not count as a vendor session (the OLED USB dot stays off). In Solid mode, SEL (index 9) follows key 0 (the key below it). Older firmware without minor 7 ignores the command.

### PREVIEW_CLOCK (0x18)

Shows or hides a clock preview on the OLED. Send `1` to show, `0` to hide. The Tauri app uses this when the user is editing clock settings so they can see the result live on the pad. Does not mark flash dirty.

---

## Packed Flash Store

Profiles, macros, and typed strings share a **packed ping-pong slot** in flash (about 4076 bytes after clock snapshots). The current magic is `LPAI` (`0x4C504149`). The bootloader migrates legacy `LPAH` (`0x4C504148`, fixed 4-profile) stores into the packed layout on first boot. Older `LPAG` / `LPAF` stores are discarded.

Up to 255 profiles, 9 keys per profile, 12 actions per key, and 240 bytes of type-text per key. Empty keys take no flash space. Factory still ships four empty profiles; **+ New** adds more until the 4 KB slot fills.

`ACT_TEXT` (`8`) is a macro step that types a string as US-HID taps, so later steps can be Enter or a chord. Keys that still have text but no `ACT_TEXT` action play the string after the other actions (older saves).

Structs are in `03 Firmware/Firmware/Core/Inc/storage.h`. The OLED USB dot blinks while a vendor command was seen in the last 2 seconds.

---

## Host-Side Behavior

The pad keeps sending keyboard/mouse/media reports (1–3) while the app holds report 4. The two paths are independent.

**KEY_EVENT** lets the Tauri app launch host programs on key press; that mapping lives in `launches.json` on the PC, not in flash. The app can also watch the focused Windows program and send `SET_ACTIVE` to auto-switch profiles (rules in `profile-rules.json`, not flash).

**SET_HOST** tells the pad whether the Windows session is in use or away, so the home screen can show the profile name or the clock, and sleep can engage.

**SET_TIME** loads the host's local wall clock. The pad then keeps time on its own (STM32 RTC from the 8 MHz crystal) for as long as it has USB power; it does not need the app connected. There is no 32 kHz backup crystal or battery, so a full unplug still loses the seconds the pad was off; a flash snapshot restores the last saved time. Until the first sync, the display starts at 16 Aug 2026 00:00:00. Open the app now and then if it has drifted.

---

## Field Firmware Update

The STM32F103C8 ROM bootloader is USART-only — no USB DFU. Updates go through a 4 KB HID bootloader at `0x08000000` (product **LogicPad Boot**, PID `0x5751`). The application stays at `0x08001000` (52 KB). Config store is unchanged at `0x0800E000`.

**Once:** flash `LogicPad_factory.hex` with ST-Link (bootloader + app). After that, the Tauri app **Update firmware** writes `LogicPad.bin` (app only) over vendor report 4.

**Recovery:** hold **SEL** while plugging USB. The pad stays in LogicPad Boot. The OLED shows **BOOT** / **USB FLASH**, then a progress bar while the image writes.

A software reset (in-app **Update firmware**) also stays in the updater. That bootloader behavior is part of `LogicPad_factory.hex` (ST-Link once); **Update firmware** only writes the app.

### Bootloader Vendor Commands

| Cmd | Name | Host → boot | Boot → host |
|-----|---|---|---|
| 0x01 | PING | — | `0x01, 0x01, 0x00, 0x42` |
| 0x40 | BL_START | size u32le, CRC-32 IEEE u32le | status, size echoed |
| 0x41 | BL_DATA | up to 62 payload bytes | status, bytes written |
| 0x42 | BL_FINISH | — | status (CRC + vector check), then jump to app |
| 0x43 | BL_ABORT | — | status, jump if app valid |

**Bootloader PING** returns `0x01` (major), `0x01` (command echo), `0x00` (status), `0x42` (signature). This is different from the application PING.

**Status codes:** `0` = ok, `1` = bad size, `2` = bad vectors (not an app image), `3` = flash error, `4` = CRC mismatch, `5` = wrong state (e.g. `BL_DATA` before `BL_START`).

The first `BL_DATA` chunk validates the vector table (stack pointer in SRAM, reset vector in app range). If the vectors are bad, the bootloader rejects the image immediately.

Do not send `LogicPad_factory.bin` through the updater — that image includes the bootloader and would be rejected by the vector check.

---

## Keyboard Usages

Factory keys ship empty. Common HID usages when assigning keys:

| Key | Usage | Key | Usage |
|-----|---|-----|---|
| A–Z | `0x04`–`0x1D` | Tab | `0x2B` |
| Esc | `0x29` | Enter | `0x28` |
| Space | `0x2C` | Backspace | `0x2A` |

**Modifier bits** (byte 1 of report 1): LCtrl = bit 0, LShift = bit 1, LAlt = bit 2, LWin/LGUI = bit 3. A Win tap is `mods = 0x08` with HID usage `0` (not usage `0xE3`).

**Consumer usages** (report 3): Prev Track `0xB6`, Next Track `0xB5`, Play/Pause `0xCD`.

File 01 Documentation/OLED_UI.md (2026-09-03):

# OLED UI

This document describes every screen, menu, and interaction on the LogicPad OLED display. The firmware source of truth is `03 Firmware/Firmware/Core/Src/ui.c`.

---

## Display Hardware

The display is a 0.96-inch SSD1306 with 128×64 pixels. It is a **dual-color** panel: the top portion is blue and the bottom 16 rows are yellow. The yellow strip is physically fixed at the bottom of the enclosure — it cannot be moved or resized in software.

| Band | Framebuffer rows | Typical use |
|---|---|---|
| Blue | 0–47 | Menus, values, key grids, main content |
| Yellow | 48–63 | Page titles, status indicators (`*` dirty flag, USB dot), short hints |

The default orientation (`SEG A0` + `COM C0`) keeps text upright relative to the physical keys. The **Screen → Flip** setting rotates the display 180° if the pad is mounted upside-down.

### Fonts

The yellow band uses the 6×8 pixel font (Font_6x8). The blue band uses a doubled 12×16 font for list rows — three rows of 16 pixels fill the entire 48-pixel blue area. The key-press toast also uses 12×16 glyphs: names of 10 characters or fewer appear on a single centered line; longer names (up to 12 characters) are split across two lines, breaking at a space if one exists, otherwise at the midpoint.

---

## Controls

### Live mode

In live mode (the normal operating state), pressing any of the nine pad keys (0–8) fires that key's macro sequence. Factory-fresh pads have no macros assigned. The **SEL** button below the grid has two functions:

- **Short press** opens the main menu.
- **Long press** (500 ms) returns to the home screen.

### Home screen

The home screen adapts based on USB and host state:

- **USB connected and PC session active:** the blue band shows a 3×3 grid of key labels (drawn from each key's title), and the yellow band shows the active profile name.
- **USB disconnected, suspended, or PC session locked/logged off:** the display switches to a standby clock showing `HH:MM:SS` and a date line (`16 Aug 2026` by default). The yellow band plays an animated band effect (see Screen settings below).

Until the host sends a `SET_TIME` command, the clock starts at 16 August 2026 00:00:00. After the first sync, the pad keeps time on its own STM32 RTC for as long as it has USB power. The companion app can also trigger a live clock preview on the home screen using the `PREVIEW_CLOCK` command, which temporarily overrides the normal display for 2.5 seconds.

### Sleep

When the sleep timeout expires (configurable, default 1 minute), the pad enters sleep mode. The display stays on showing the same idle home screen — it does not blank. A key press wakes the pad and the triggering key still performs its normal action: SEL opens the menu, pad keys fire their macros.

### Menu navigation

Menus use the nine-key grid as a d-pad. The four corner keys are unused except for `+` (key 2) and `−` (key 8) on the macro list screen.

```
[ ] [1 Up]   [2 +]
[3 L] [4 OK]   [5 R]
[ ] [7 Down] [8 −]
       [SEL Back / hold Home]
```

Navigation rules:

- **Key 1** moves up, **key 7** moves down, **key 3** moves left, **key 5** moves right. **Key 4** is OK / confirm.
- **SEL short press** goes Back (one level up), not Left.
- Lists do not wrap around — scrolling stops at the first and last items.
- At most three large rows are visible in the blue band at once. The highlight stays in the center row while the list scrolls around it.
- **Value screens** show the current value in the blue band (large text) with the setting name and navigation hint in the yellow band.
- **Save prompt:** pressing OK saves changes to flash; pressing SEL discards them.

### Adding macro actions

When editing a key's macro, pressing `+ Add` presents five action kinds:

- **Key** — a letter key (A–Z). After selecting a letter, choose Tap, Hold, or Release.
- **Sys** — a system key: Tab, Win, Alt, Ctrl, Shift, Esc, Enter, Space, or Backspace.
- **Mouse** — Button (left click), Move (10 px right), or Wheel (one tick up).
- **Wait** — a delay in 10 ms increments (50 ms to 250 ms).
- **Text** — plays the key's type-text string, which is edited in the companion app.

### Key picker

The key picker screen (under Keys) displays "Press a key". Pressing any of the nine pad keys selects that key for editing — the key literally picks itself.

---

## Screen Map

The firmware defines 37 screens. Their internal names are:

`boot`, `home`, `toast`, `menu`, `profList`, `profActs`, `profName`, `profReset`, `profDel`, `keyPick`, `keyEdit`, `keyName`, `keyLight`, `macroView`, `addKind`, `addLetter`, `addSend`, `addSys`, `addMouse`, `addWait`, `setup`, `lightsHub`, `lightMode`, `lightBright`, `lightDim`, `screenHub`, `scrContrast`, `scrFlip`, `scrSleep`, `clkStyle`, `clkSpeed`, `clkBar`, `about`, `saved`, `resetAll`, `sleeping`, `savePrompt`.

### Firmware update screens

When the host sends an `ENTER_BOOTLOADER` command, the app firmware draws **FLASH** in blue and **BOOT MODE** in yellow, then resets into the HID bootloader. The bootloader has its own separate screens — **BOOT** / **USB FLASH**, a progress bar, and finally **OK** or **FAIL**. These bootloader screens are part of `LogicPad_factory.hex` (flashed once via ST-Link) and are not included in the application `.bin`.

---

## Menu Structure

The main menu has three entries: **Profiles**, **Keys**, and **Setup**. Setup leads to three sub-menus: **Lights**, **Screen**, and **About**.

### Profiles

The profile list shows all stored profiles with the active one marked by `*`. If flash has room, a **+ New** entry appears at the end. Selecting a profile opens its action menu:

- **Use** — switches to this profile and returns home.
- **Rename** — opens a character-by-character name editor (A–Z, a–z, 0–9, space; up/down scrolls the current character).
- **Reset** — clears all key assignments for this profile (requires confirmation).
- **Delete** — removes the profile entirely (only available when more than one profile exists; requires confirmation, same as Reset).

Empty keys consume no flash space.

### Keys

Selecting **Keys** from the main menu enters the key picker. Pressing a pad key opens that key's edit screen with three options:

- **Name** — sets the 12-character display title shown on the home grid and toast.
- **Light** — sets the per-key LED color (Off, White, Red, Green, Blue).
- **Macro** — opens the action list for that key, where actions can be added, reordered, or deleted.

### Screen settings

The Screen sub-menu has six value screens, each showing one setting at a time:

| Setting | Values | Default |
|---|---|---|
| Contrast | 0–10 (maps to hardware PWM) | 5 |
| Flip | Off / On (180° rotation) | Off |
| Sleep | Never, 15 s, 30 s, 1 min, 5 min | 1 min |
| Style | Bounce, Scan, March, Pulse, Wave, Blocks, Comet, Swing, Fill, Sparkle, Ripple, Rain, Off | Bounce |
| Speed | Slow (32 ms), Normal (16 ms), Fast (8 ms), Rapid (4 ms) | Normal |
| Bar | Off / On (seconds progress bar across the clock band) | On |

The Style, Speed, and Bar settings control the animated band in the yellow strip during the standby clock. The companion app can set all of these remotely via `SET_SCREEN` and preview the clock live with `PREVIEW_CLOCK`.

### Lights settings

The Lights sub-menu has three value screens:

- **Mode** — the LED animation pattern. Fifteen modes are available: Off, Solid, React, Breathe, Wave, Ring, Ripple, Rain, Heart, Cross, Twinkle, Full White, Full Red, Full Green, Full Blue.
- **Bright** — maximum LED intensity (0–10).
- **Dim** — idle LED intensity (0–10).

LED behavior notes:

- Animation shows paint their own colors — they do not require per-key LED assignments.
- **Full White / Full Red / Full Green / Full Blue** illuminate all nine keys plus the selector LED simultaneously without the usual 1/9 scan multiplexing. These modes stay at the Bright level and do not fall back to Dim.
- **React** flashes the pressed key's LED, even if the key has no macro assigned.
- **Ripple** spreads outward from the pressed key, including when SEL is pressed.
- The selector RGB LED sits above key 1 and participates in all animations. In Solid mode it matches key 1's color.
- The companion app's **Key LEDs** grid mirrors the same physical layout. With firmware minor version 7 or later, the app can read live LED colors via `GET_LEDS`.

### About

The About screen shows the USB connection status, a **Save** option (persists all changes to flash), and a **Reset** option (restores factory defaults and saves).

---

## Timing Reference

| Event | Duration |
|---|---|
| SEL long-press threshold | 500 ms |
| Key hold-repeat delay | 400 ms, then 12 repeats/sec |
| Boot splash | 900 ms |
| Key-press toast | 700 ms |
| Menu idle timeout | 15 s, 30 s (default), 60 s |
| Live sleep timeout | Never, 15 s, 30 s, 1 min (default), 5 min |

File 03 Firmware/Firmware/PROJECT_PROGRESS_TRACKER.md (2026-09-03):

# LogicPad firmware progress

Agent continuation (locks + next steps): [`AGENTS.md`](../../AGENTS.md) at repo root.

## Done in code (v0.1)

- [x] GPIO: columns PB3/4/5 outputs (idle high), rows PB12/13/14 input pull-up, Selector PB15 pull-up
- [x] 1 ms keypad scan, debounce, SEL short/long, hold-repeat
- [x] SSD1306 I2C UI (all planned screens, Font_6x8 + 2× lists)
- [x] USB Custom HID: keyboard + mouse + consumer + vendor (report IDs 1–4)
- [x] Macro engine + CRC ping-pong flash (last 8 KB at `0x0800E000`; app FLASH = 52 KB at `0x08001000`)
- [x] Per-key RGB mux from Lights / key LED color
- [x] Tauri configurator (`04 Software/logicpad-app/` — connect, profiles, keys, save, firmware update, drag-drop launch, type-text, memory meter)
- [x] HID field update (`03 Firmware/bootloader/`, PID `0x5751`; first flash `LogicPad_factory.hex`, then app `LogicPad.bin`; OLED boot screens + in-app reset from main loop)
- [x] Idle OLED clock (24h `HH:MM:SS`, date `16 Aug 2026`; SET_TIME `0x0E` from the app; HSE RTC keeps time while powered, flash snapshot across power loss)
- [x] Idle home shows the active profile while USB is live; clock when USB is down or SET_HOST `0x15` reports the PC locked / logged off
- [ ] Own VID/PID (still ST test IDs 1155/22352 app, 22353 boot)

## How to use

Plug USB in. Windows/macOS/Linux see a keyboard. Factory profiles P1–P4 have no macros assigned; add more on the OLED until flash is full.

SEL opens the OLED menu. Configure profiles, keys, macros, lights, and screen on the device. No PC app required.

## Build

STM32CubeIDE or CMake preset `Release` in `03 Firmware/Firmware/` (arm-none-eabi-gcc + Ninja), after building `03 Firmware/bootloader` Release. First flash: `LogicPad_factory.hex` with ST-Link. Later: Tauri **Update firmware** + `LogicPad.bin`. Do not regenerate CubeMX over USER CODE; rows must stay inputs.

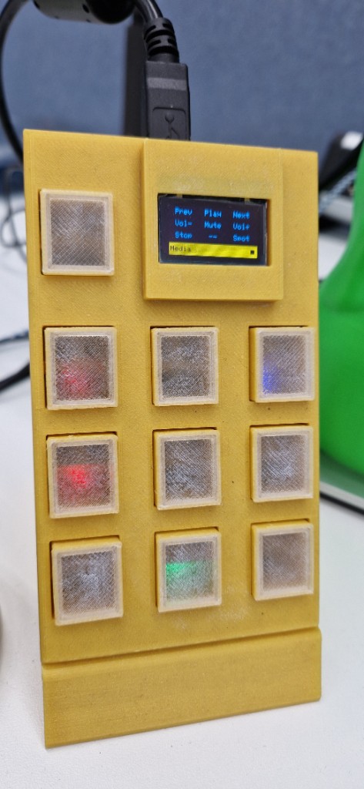
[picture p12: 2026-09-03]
.github/assets/hero-source.jpg

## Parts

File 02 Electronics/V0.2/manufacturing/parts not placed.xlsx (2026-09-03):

Designator | Comment | Footprint | Quantity
R7 | 453K | R_0603_1608METRIC | 1
U2 | TLV62568DBV | SOT-23-5 | 1
F1 | FUSE | FUSE_1206_3216METRIC | 1
J2 | USB_B | USB_B_OST_USB-B1HSXX_HORIZONTAL | 0
TP11,TP10,TP9,TP8,TP7,TP6,TP5,TP4,TP3,TP2,TP1 | TESTPOINT_PROBE | TESTPOINT_PAD_D1.5MM | 0
D10,D9,D8,D7,D6,D5,D4,D3,D2,D1 | RGB_LED | SMD | 0
SW1,SW7,SW8,SW10,SW9,SW6,SW5,SW4,SW3,SW2 | SW_PUSH | SMD | 0
L1 | 1UH | SRN3012TA-1R0Y | 0
J3,J1 | CONN_01X04 | PINHEADER_1X04_P2.54MM_VERTICAL | 0
DESIGNATOR | COMMENT | FOOTPRINT | 0

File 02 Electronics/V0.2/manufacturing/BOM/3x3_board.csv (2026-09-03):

Id | Designator | Package | Quantity | Designation | Supplier and ref
1 | SW1,SW7,SW8,SW10,SW9,SW6,SW5,SW4,SW3,SW2 | gateronSwitch | 10 | SW_Push
2 | R8 | R_0603_1608Metric | 1 | 100K
3 | R7 | R_0603_1608Metric | 1 | 453K
4 | Q2,Q3,Q1 | SOT-23 | 3 | 2N7002
5 | C9,C8,C7,C6,C5,C4,C3 | C_0603_1608Metric | 7 | 100n
6 | TP11,TP10,TP9,TP8,TP7,TP6,TP5,TP4,TP3,TP2,TP1 | TestPoint_Pad_D1.5mm | 11 | TestPoint_Probe
7 | Y1 | Crystal_SMD_5032-2Pin_5.0x3.2mm | 1 | 8Mhz
8 | R74,R73,R72,R69,R68,R67,R64,R63,R62,R59,R58,R57,R54,R53,R52,R49,R48,R47,R44,R43,R42,R39,R38,R37,R34,R33,R32,R29,R28,R27 | R_0603_1608Metric | 30 | 165
9 | R71,R66,R61,R56,R51,R46,R41,R36,R31,R26,R5,R3,R1 | R_0603_1608Metric | 13 | 100
10 | R70,R65,R60,R55,R50,R45,R40,R35,R30,R25,R6,R4,R2 | R_0603_1608Metric | 13 | 47k
11 | Q13,Q12,Q11,Q10,Q9,Q8,Q7,Q6,Q5,Q4 | SOT-23 | 10 | BSS84
12 | D10,D9,D8,D7,D6,D5,D4,D3,D2,D1 | 2020_RGB | 10 | RGB_LED
13 | J2 | USB_B_OST_USB-B1HSxx_Horizontal | 1 | USB_B
14 | U2 | SOT-23-5 | 1 | TLV62568DBV
15 | U1 | LQFP-48_7x7mm_P0.5mm | 1 | STM32F103C8Tx
16 | R22 | R_0603_1608Metric | 1 | 10K
17 | R21,R20 | R_0603_1608Metric | 2 | 22
18 | L1 | SRN3012TA-1R0Y | 1 | 1uH
19 | J3,J1 | PinHeader_1x04_P2.54mm_Vertical | 2 | Conn_01x04
20 | F1 | Fuse_1206_3216Metric | 1 | Fuse
21 | C11 | C_0805_2012Metric | 1 | 22uF
22 | C10 | C_1206_3216Metric | 1 | 4.7uF
23 | C2,C1 | C_0603_1608Metric | 2 | 12pF

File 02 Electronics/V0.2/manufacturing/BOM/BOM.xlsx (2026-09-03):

Comment | Designator | Footprint
SW_Push | SW1,SW7,SW8,SW10,SW9,SW6,SW5,SW4,SW3,SW2 | SMD
100K | R8 | R_0603_1608Metric
453K | R7 | R_0603_1608Metric
2N7002 | Q2,Q3,Q1 | SOT-23
100n | C9,C8,C7,C6,C5,C4,C3 | C_0603_1608Metric
TestPoint_Probe | TP11,TP10,TP9,TP8,TP7,TP6,TP5,TP4,TP3,TP2,TP1 | TestPoint_Pad_D1.5mm
8Mhz | Y1 | Crystal_SMD_5032-2Pin_5.0x3.2mm
165 | R74,R73,R72,R69,R68,R67,R64,R63,R62,R59,R58,R57,R54,R53,R52,R49,R48,R47,R44,R43,R42,R39,R38,R37,R34,R33,R32,R29,R28,R27 | R_0603_1608Metric
100 | R71,R66,R61,R56,R51,R46,R41,R36,R31,R26,R5,R3,R1 | R_0603_1608Metric
47k | R70,R65,R60,R55,R50,R45,R40,R35,R30,R25,R6,R4,R2 | R_0603_1608Metric
BSS84 | Q13,Q12,Q11,Q10,Q9,Q8,Q7,Q6,Q5,Q4 | SOT-23
RGB_LED | D10,D9,D8,D7,D6,D5,D4,D3,D2,D1 | SMD
USB_B | J2 | USB_B_OST_USB-B1HSxx_Horizontal
TLV62568DBV | U2 | SOT-23-5
STM32F103C8Tx | U1 | LQFP-48_7x7mm_P0.5mm
10K | R22 | R_0603_1608Metric
22 | R21,R20 | R_0603_1608Metric
1uH | L1 | SRN3012TA-1R0Y
Conn_01x04 | J3,J1 | PinHeader_1x04_P2.54mm_Vertical
Fuse | F1 | Fuse_1206_3216Metric
22uF | C11 | C_0805_2012Metric
4.7uF | C10 | C_1206_3216Metric
12pF | C2,C1 | C_0603_1608Metric

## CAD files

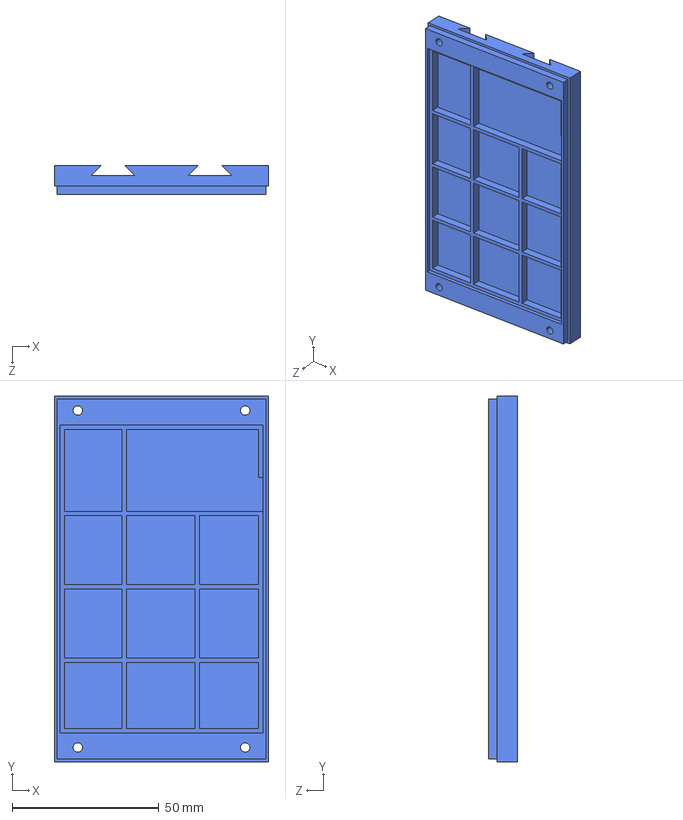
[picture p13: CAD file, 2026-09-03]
05 Hardware/Case Part A.STEP
73.1 x 124.8 x 10.0 mm

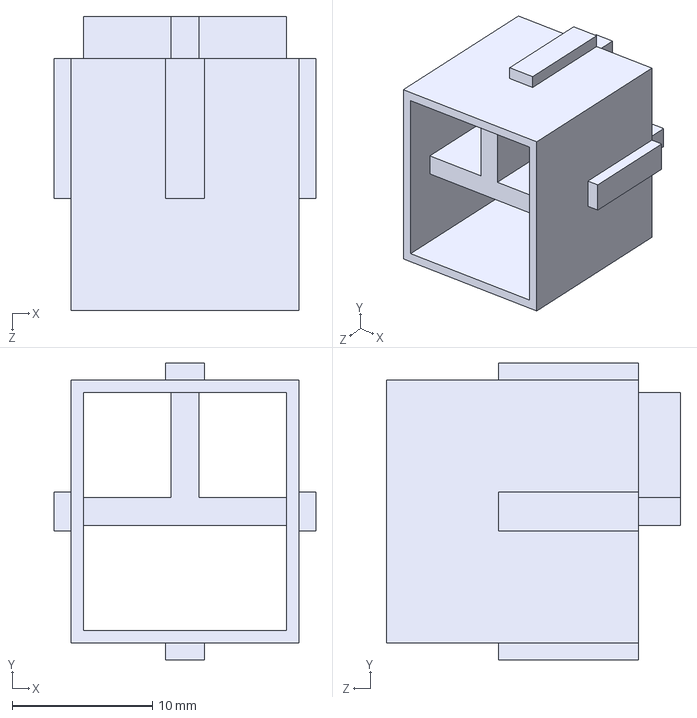
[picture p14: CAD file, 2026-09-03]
05 Hardware/Button.STEP
18.7 x 21.2 x 21.0 mm

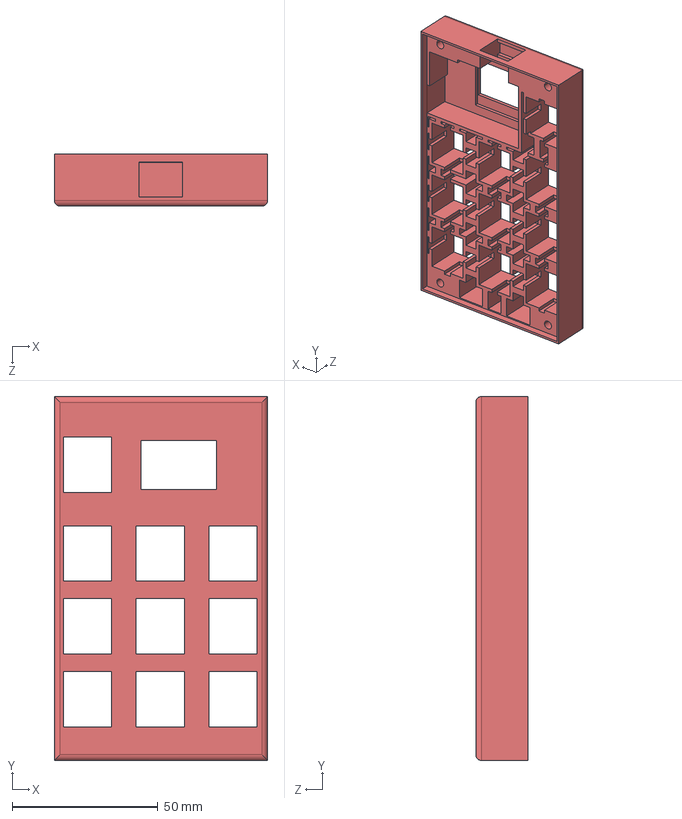
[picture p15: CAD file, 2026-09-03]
05 Hardware/Case Part B.STEP
73.1 x 124.8 x 18.0 mm

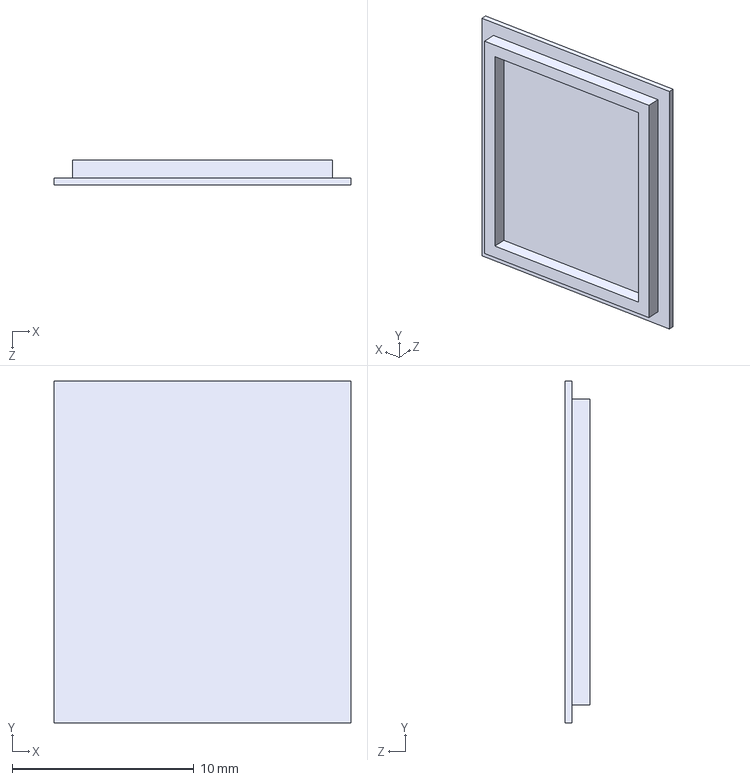
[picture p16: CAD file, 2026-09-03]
05 Hardware/Button Cap.STEP
16.3 x 18.8 x 1.40 mm

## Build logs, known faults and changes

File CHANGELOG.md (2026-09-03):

# Changelog

All notable changes to this project are documented here.

## v0.1.0 — 2026-08-31

First public release.

### LogicPad companion app (Windows)

- Profile and key editor with live pad sync
- YAML setup packs (Save as / Import)
- Auto-switch profiles with node-graph editor
- Drag-and-drop PC program launch mappings
- USB firmware update via HID bootloader
- Virtual keypad for drafting setups without hardware

### Firmware

- Plug-and-use USB HID macro pad (keyboard, mouse, media)
- Full OLED on-device editor (profiles, macros, lighting)
- 4 KB HID bootloader for field updates
- Packed flash store with multiple profiles

### Hardware

- KiCad V0.2 board design, BOM, and manufacturing outputs

### Downloads

| Platform | File | Notes |
|---|---|---|
| **Windows** | `LogicPad_*_x64-setup.exe` | Recommended NSIS installer (per-user, no admin) |
| **Windows** | `LogicPad-windows-x64.exe` | Portable build |
| **macOS** | `LogicPad_*_x64.dmg` | Drag **LogicPad** to Applications |
| **Linux** | `LogicPad_*_amd64.AppImage` | `chmod +x` then run; udev rule still needed for USB |
| **Linux** | `logicpad-app_*_amd64.deb` | Debian / Ubuntu package |
| **All** | `LogicPad-Productivity.yaml` | Example profile pack (Import in the app) |

Releases are built for **Windows, macOS, and Linux** when you push a `v*` tag (see `.gitea/workflows/release.yml`).

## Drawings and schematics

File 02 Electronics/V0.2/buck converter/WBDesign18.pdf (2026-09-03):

## WEBENCH ® Design Report

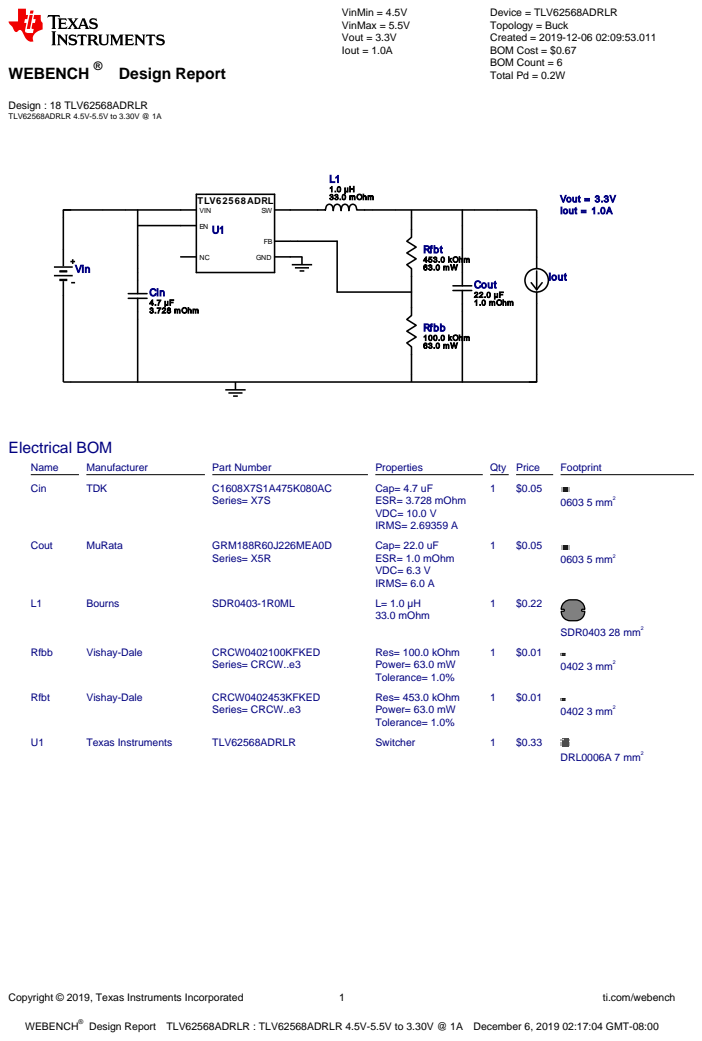
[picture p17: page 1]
Copyright © 2019, Texas Instruments Incorporated; ti.com/webench; WEBENCH®; Design : 18 TLV62568ADRLR TLV62568ADRLR 4.5V-5.5V to 3.30V @ 1A; VinMin = 4.5V VinMax = 5.5V Vout = 3.3V Iout = 1.0A; Device = TLV62568ADRLR Topology = Buck Created = 2019-12-06 02:09:53.011 BOM Cost = $0.67 BOM Count = 6 Total Pd = 0.2W; Vout = 3.3V Iout = 1.0A; TLV62568ADRL; GND; VIN; Cin 4.7 µF 3.728 mOhm; Rfbb 100.0 kOhm 63.0 mW; Rfbt 453.0 kOhm 63.0 mW; L1 1.0 µH 33.0 mOhm; Cout 22.0 µF 1.0 mOhm; Vin; Iout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

Design Report TLV62568ADRLR : TLV62568ADRLR 4.5V-5.5V to 3.30V @ 1A December 6, 2019 02:17:04 GMT-08:00

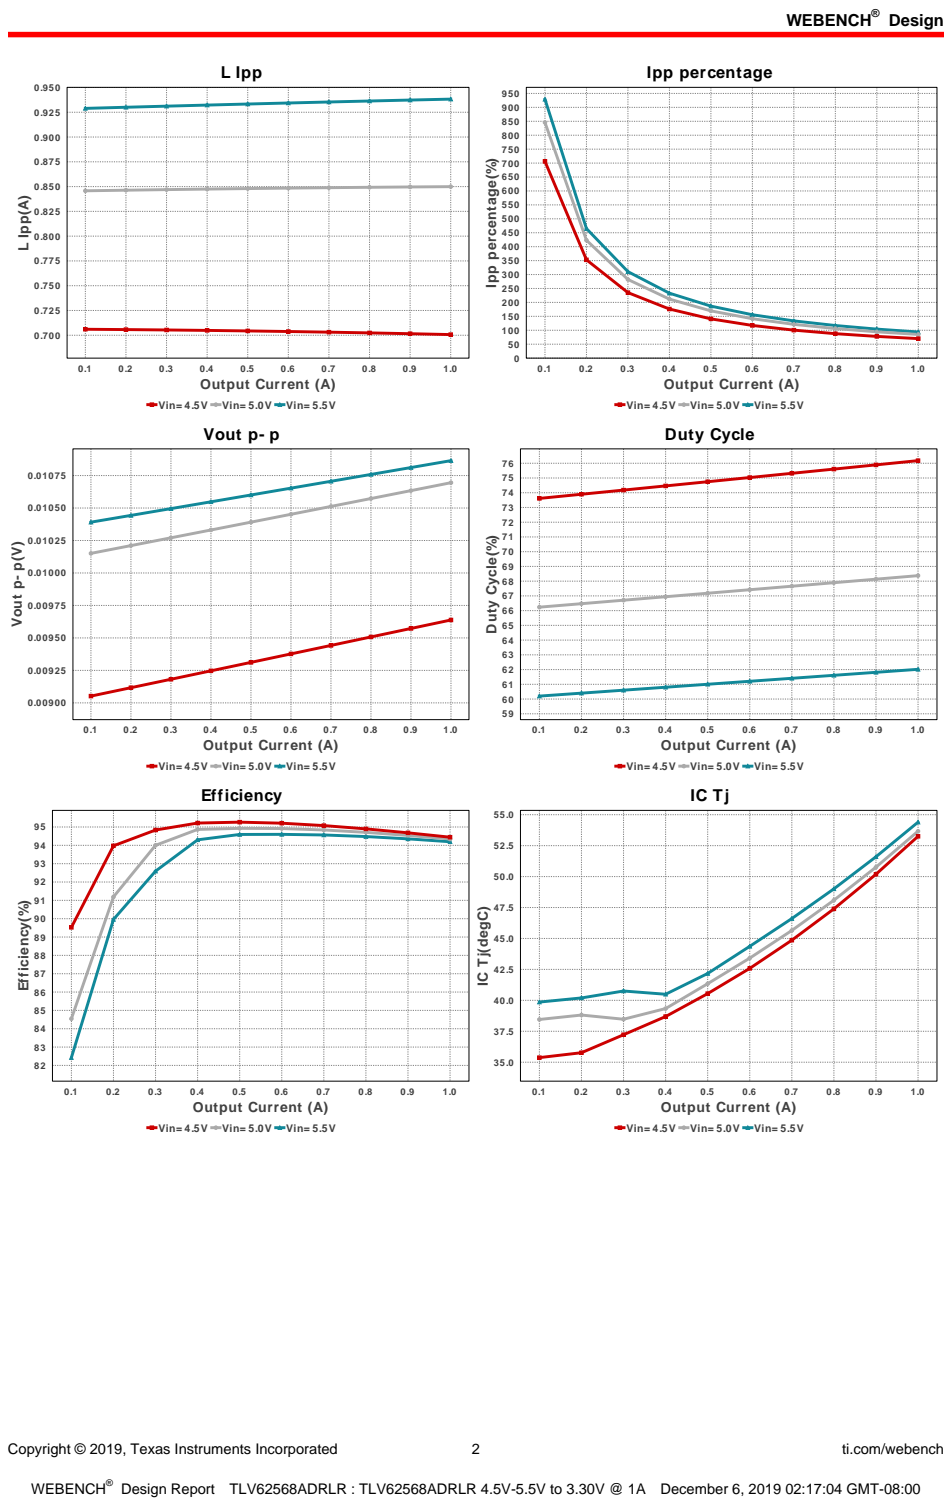
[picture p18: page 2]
Design; Copyright © 2019, Texas Instruments Incorporated; ti.com/webench; L Ipp; 1.0 Output Current (A); L Ipp(A); Ipp percentage; Ipp percentage(%); Vout p- p(V); Duty Cycle(%); Efficiency(%)

Vin= 4.5V Vin= 5.0V Vin= 5.5V
Vout p- p

Duty Cycle

Efficiency

IC Tj(degC)

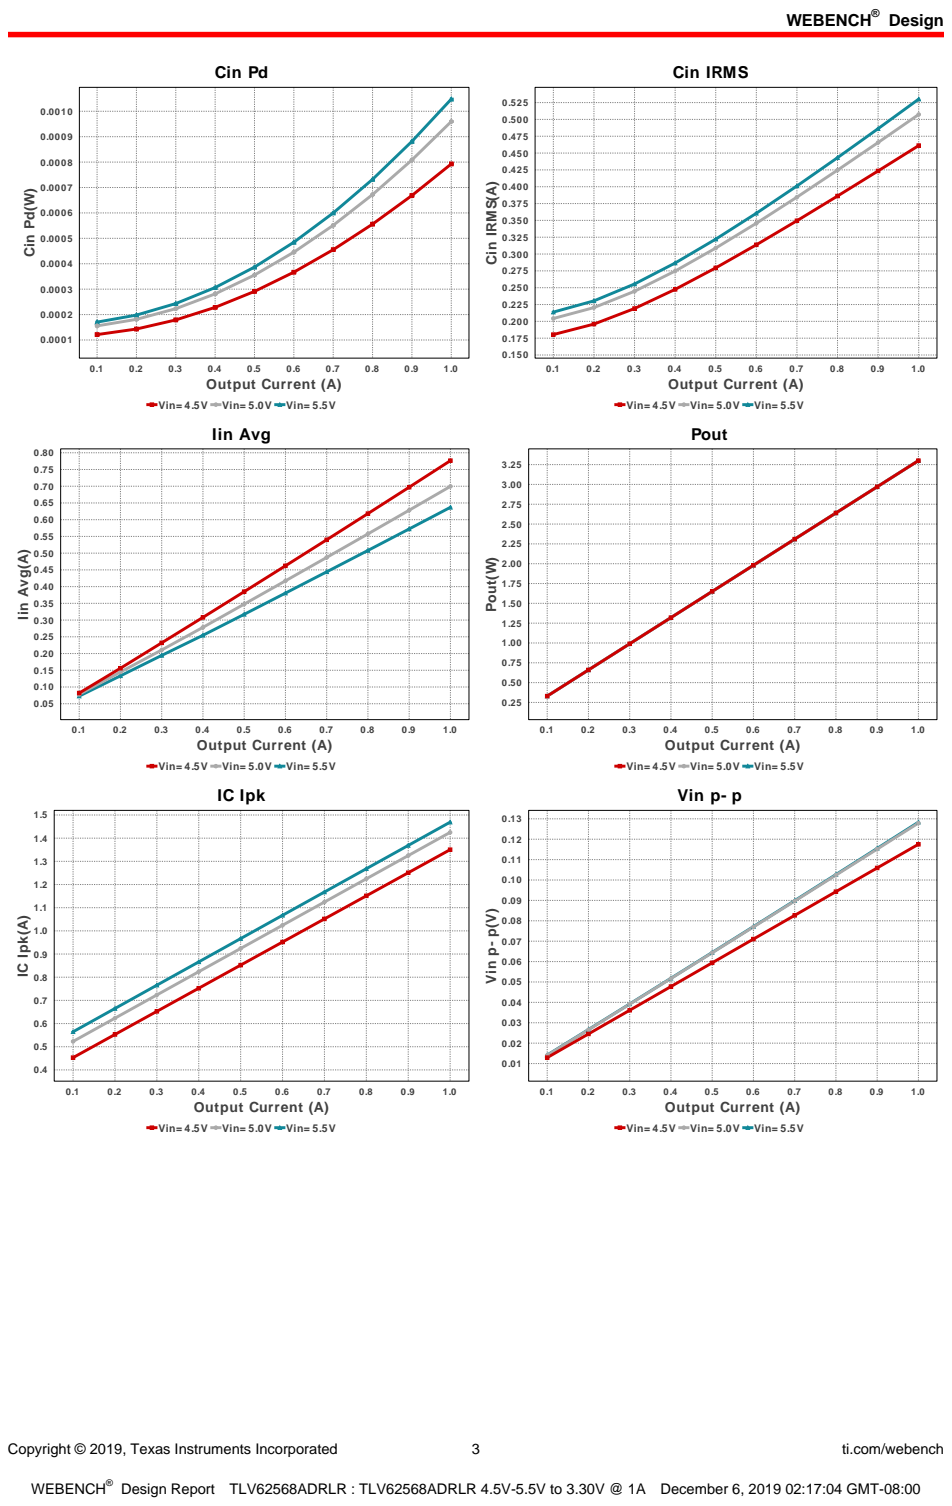
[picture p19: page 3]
Copyright © 2019, Texas Instruments Incorporated; ti.com/webench; Cin Pd; 1.0 Output Current (A); Cin Pd(W); Cin IRMS; Cin IRMS(A); Iin Avg(A); Pout; Pout(W); IC Ipk; IC Ipk(A); Vin p- p(V)

Vin= 4.5V Vin= 5.0V Vin= 5.5V
Iin Avg

Vin p- p

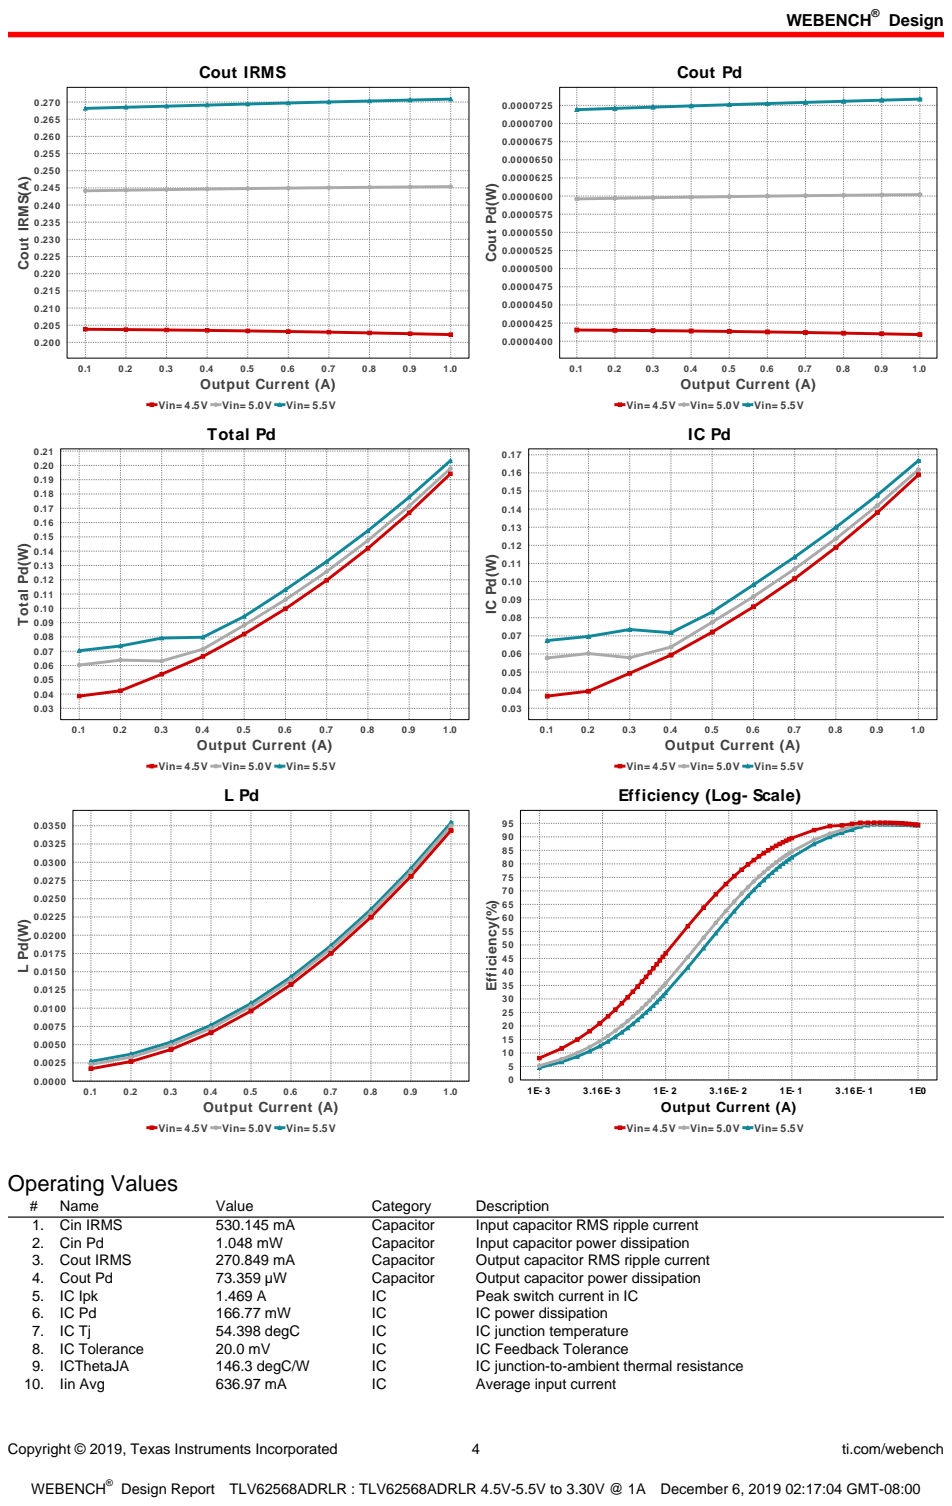
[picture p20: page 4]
Copyright © 2019, Texas Instruments Incorporated; ti.com/webench; Cout IRMS; 1.0 Output Current (A); Cout IRMS(A); Cout Pd; Cout Pd(W); Total Pd(W); 1E0 Output Current (A); Efficiency(%); Operating Values; Name; Value; Category; Description; 1. Cin IRMS; Capacitor; Input capacitor RMS ripple current; 2. Cin Pd; Input capacitor power dissipation; 3. Cout IRMS; Output capacitor RMS ripple current; 4. Cout Pd; Output capacitor power dissipation; 5. IC Ipk; Peak switch current in IC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

Vin= 4.5V Vin= 5.0V Vin= 5.5V
Total Pd

Efficiency (Log- Scale)

Copyright © 2019, Texas Instruments Incorporated | 5 | ti.com/webench
# | Name | Value | Category | Description

11. Ipp percentage | 93.825 % | Inductor | Inductor ripple current percentage (with respect to average inductor
| | | | current)
12. L Ipp | 938.25 mA | Inductor | Peak-to-peak inductor ripple current
13. L Pd | 35.421 mW | Inductor | Inductor power dissipation
14. Cin Pd | 1.048 mW | Power | Input capacitor power dissipation
15. Cout Pd | 73.359 µW | Power | Output capacitor power dissipation
16. IC Pd | 166.77 mW | Power | IC power dissipation
17. L Pd | 35.421 mW | Power | Inductor power dissipation
18. Total Pd | 203.299 mW | Power | Total Power Dissipation
19. BOM Count | 6 | System
| | | Information | Total Design BOM count
20. Duty Cycle | 62.018 % | System
| | | Information | Duty cycle
21. Efficiency | 94.197 % | System
| | | Information | Steady state efficiency
22. FootPrint | 50.0 mm² | System
| | | Information | Total Foot Print Area of BOM components
23. Frequency | 1.369 MHz | System
| | | Information | Switching frequency
24. Iout | 1.0 A | System
| | | Information | Iout operating point
25. Mode | CCM | System
| | | Information | Conduction Mode
26. Pout | 3.3 W | System
| | | Information | Total output power
27. Total BOM | $0.67 | System
| | | Information | Total BOM Cost
28. Vin | 5.5 V | System
| | | Information | Vin operating point
29. Vin p-p | 124.798 mV | System
| | | Information | Peak-to-peak input voltage
30. Vout | 3.3 V | System
| | | Information | Operational Output Voltage
31. Vout Actual | 3.318 V | System
| | | Information | Vout Actual calculated based on selected voltage divider resistors
32. Vout Tolerance | 5.043 % | System
| | | Information | Vout Tolerance based on IC Tolerance (no load) and voltage divider resistors if applicable
33. Vout p-p | 10.874 mV | System
| | | Information | Peak-to-peak output ripple voltage

## Design Inputs

Name | Value | Description
Iout | 1.0 | Maximum Output Current
VinMax | 5.5 | Maximum input voltage
VinMin | 4.5 | Minimum input voltage
Vout | 3.3 | Output Voltage
| base_pn | | TLV62568A-DRL | Base Product Number
source | DC | Input Source Type
Ta | 30.0 | Ambient temperature


Copyright © 2019, Texas Instruments Incorporated | 6 | ti.com/webench

## Assembly
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

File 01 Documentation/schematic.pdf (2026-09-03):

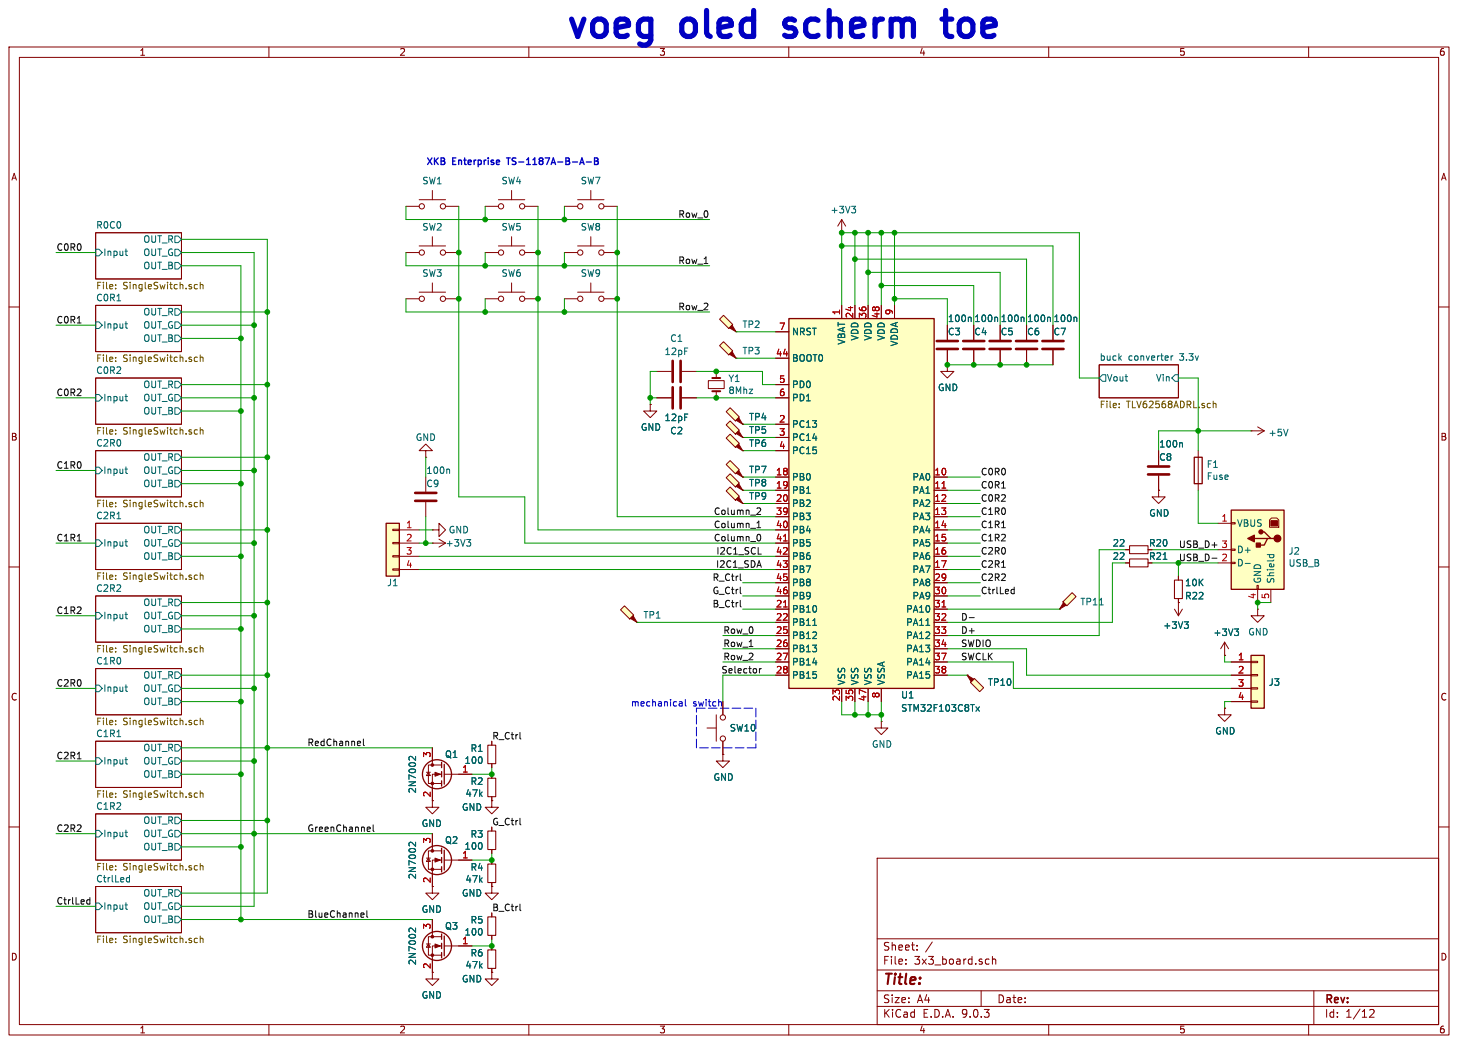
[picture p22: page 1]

OUT_B CtrlLed File: SingleSwitch.sch

Id: 1/12 Title: File: 3x3_board.sch Sheet: /

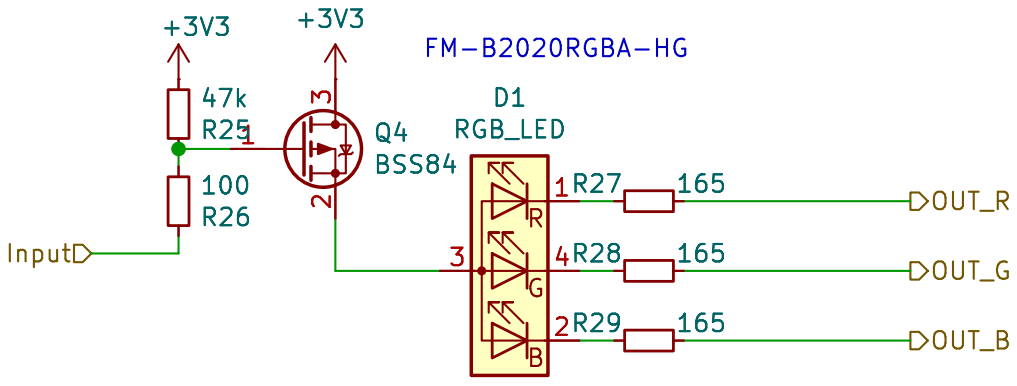
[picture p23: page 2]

Id: 2/12 Title: File: SingleSwitch.sch Sheet: /R0C0/

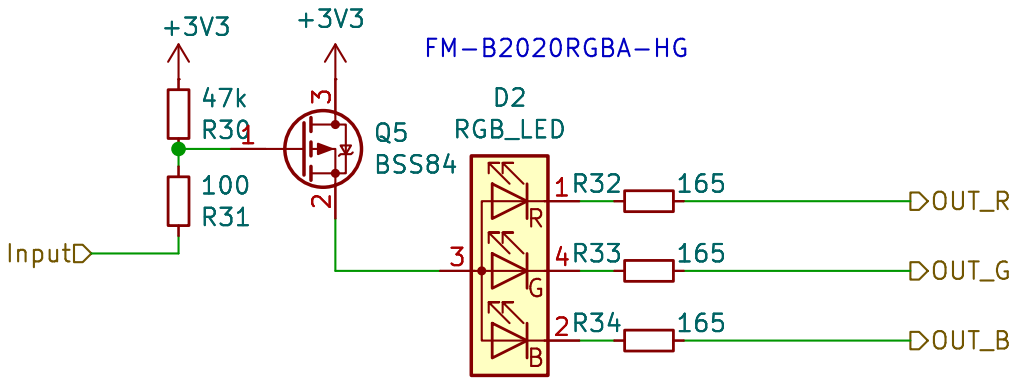
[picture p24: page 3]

Id: 3/12 Title: File: SingleSwitch.sch Sheet: /C0R1/

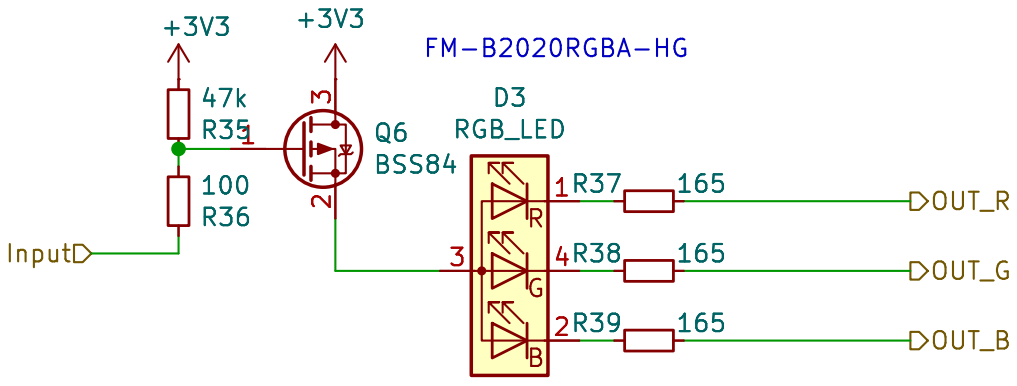
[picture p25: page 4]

Id: 4/12 Title: File: SingleSwitch.sch Sheet: /C0R2/

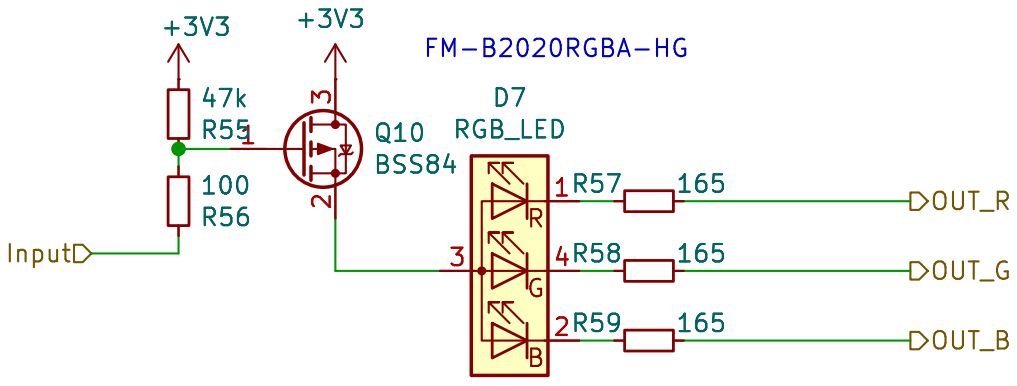
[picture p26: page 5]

Id: 5/12 Title: File: SingleSwitch.sch Sheet: /C2R0/

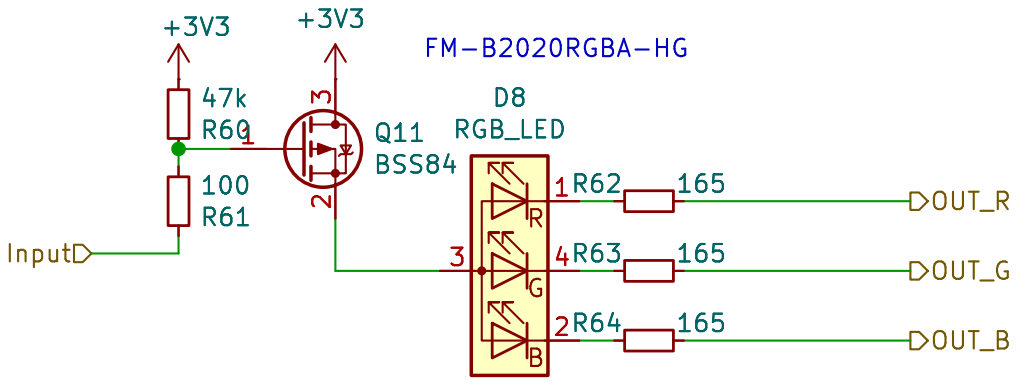
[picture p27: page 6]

Id: 6/12 Title: File: SingleSwitch.sch Sheet: /C2R1/

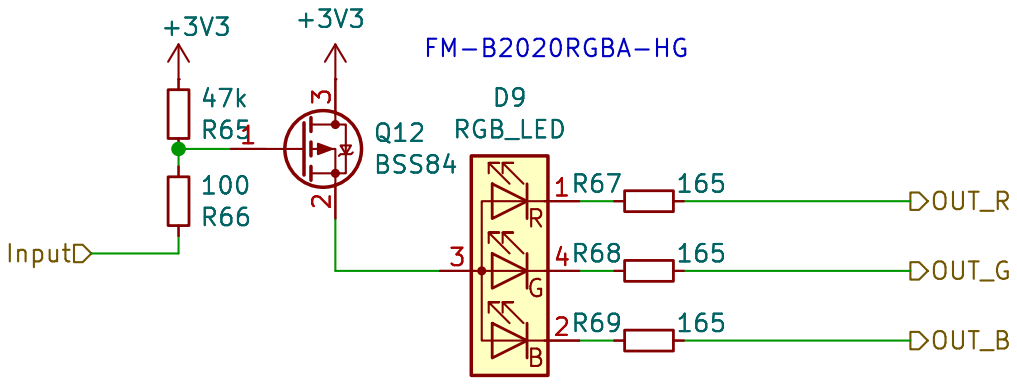
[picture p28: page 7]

Id: 7/12 Title: File: SingleSwitch.sch Sheet: /C2R2/


Id: 8/12 Title: File: SingleSwitch.sch Sheet: /C1R0/


Id: 9/12 Title: File: SingleSwitch.sch Sheet: /C1R1/


Id: 10/12 Title: File: SingleSwitch.sch Sheet: /C1R2/


Id: 11/12 Title: File: SingleSwitch.sch Sheet: /CtrlLed/


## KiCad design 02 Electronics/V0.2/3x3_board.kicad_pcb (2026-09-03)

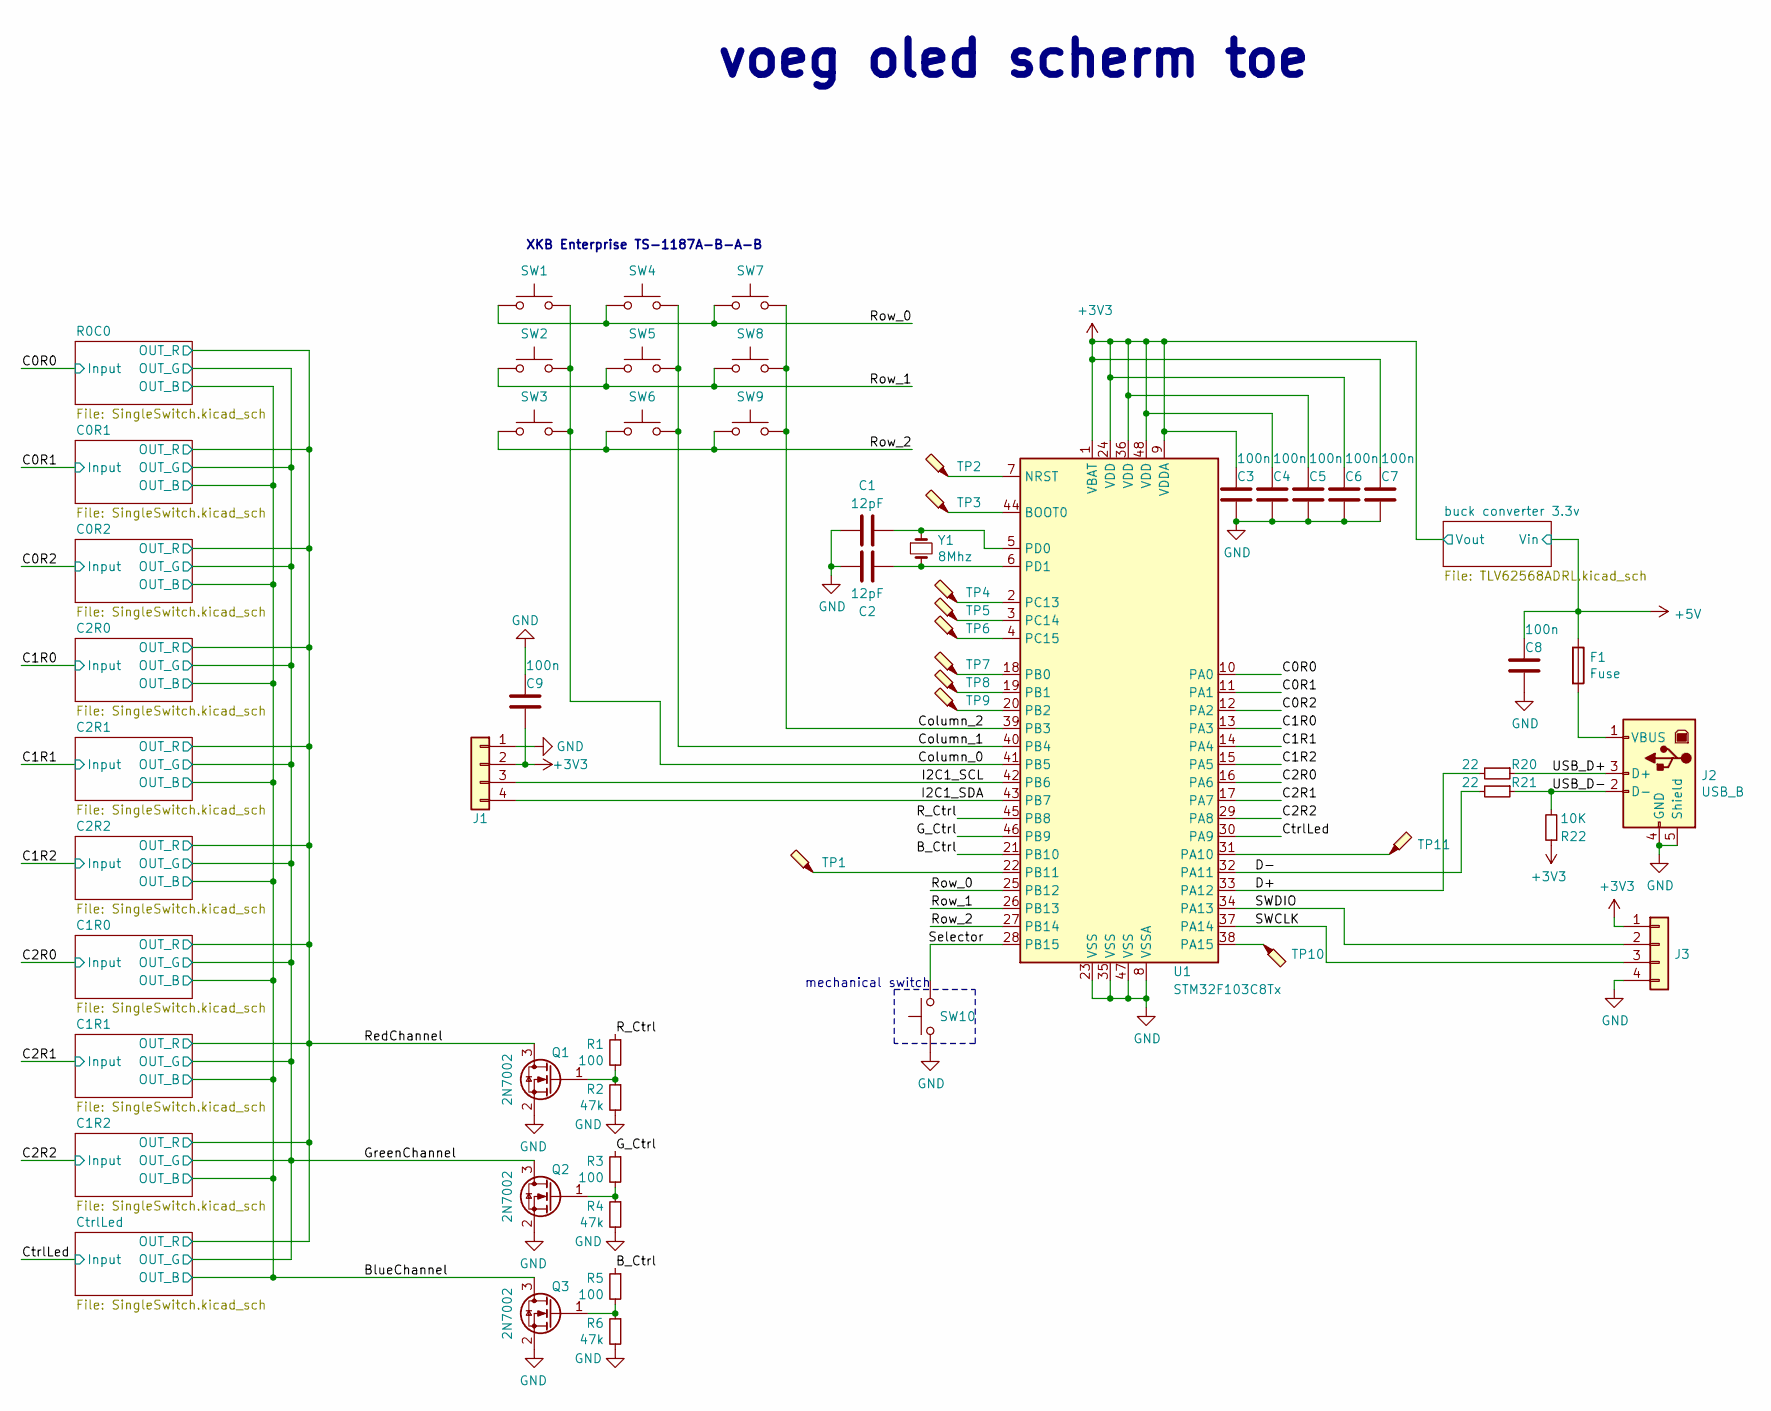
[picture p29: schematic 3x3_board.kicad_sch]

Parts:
C1, C2: 12pF; C_0603_1608Metric
C3, C4, C5, C6, C7, C8, C9: 100n; C_0603_1608Metric
F1: Fuse; Fuse_1206_3216Metric
J1, J3: Conn_01x04; PinHeader_1x04_P2.54mm_Vertical
J2: USB_B; USB_B_OST_USB-B1HSxx_Horizontal
Q1, Q2, Q3: 2N7002; SOT-23
R1, R3, R5: 100; R_0603_1608Metric
R2, R4, R6: 47k; R_0603_1608Metric
R20, R21: 22; R_0603_1608Metric
R22: 10K; R_0603_1608Metric
SW1, SW2, SW3, SW4, SW5, SW6, SW7, SW8, SW9, SW10: SW_Push; gateronSwitch
TP1, TP2, TP3, TP4, TP5, TP6, TP7, TP8, TP9, TP10, TP11: TestPoint_Probe; TestPoint_Pad_D1.5mm
U1: STM32F103C8Tx; LQFP-48_7x7mm_P0.5mm
Y1: 8Mhz; Crystal_SMD_5032-2Pin_5.0x3.2mm

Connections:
+3V3: C3.1, C4.1, C5.1, C6.1, C7.1, C9.2, J1.2, J3.1, R22.1, U1.1 (VBAT), U1.9 (VDDA), U1.24 (VDD), U1.36 (VDD), U1.48 (VDD); also elsewhere on the board
+5V: C8.1, F1.1; also elsewhere on the board
/B_Ctrl: R5.1, U1.21 (PB10)
/BlueChannel: Q3.3 (D); also elsewhere on the board
/C0R0: U1.10 (PA0); also elsewhere on the board
/C0R1: U1.11 (PA1); also elsewhere on the board
/C0R2: U1.12 (PA2); also elsewhere on the board
/C1R0: U1.13 (PA3); also elsewhere on the board
/C1R1: U1.14 (PA4); also elsewhere on the board
/C1R2: U1.15 (PA5); also elsewhere on the board
/C2R0: U1.16 (PA6); also elsewhere on the board
/C2R1: U1.17 (PA7); also elsewhere on the board
/C2R2: U1.29 (PA8); also elsewhere on the board
/Column_0: SW1.2, SW2.2, SW3.2, U1.41 (PB5)
/Column_1: SW4.2, SW5.2, SW6.2, U1.40 (PB4)
/Column_2: SW7.2, SW8.2, SW9.2, U1.39 (PB3)
/CtrlLed: U1.30 (PA9); also elsewhere on the board
/D+: R20.2, U1.33 (PA12)
/D-: R21.2, U1.32 (PA11)
/G_Ctrl: R3.1, U1.46 (PB9)
/GreenChannel: Q2.3 (D); also elsewhere on the board
/I2C1_SCL: J1.3, U1.42 (PB6)
/I2C1_SDA: J1.4, U1.43 (PB7)
/R_Ctrl: R1.1, U1.45 (PB8)
/RedChannel: Q1.3 (D); also elsewhere on the board
/Row_0: SW1.1, SW4.1, SW7.1, U1.25 (PB12)
/Row_1: SW2.1, SW5.1, SW8.1, U1.26 (PB13)
/Row_2: SW3.1, SW6.1, SW9.1, U1.27 (PB14)
/SWCLK: J3.3, U1.37 (PA14)
/SWDIO: J3.2, U1.34 (PA13)
/Selector: SW10.2, U1.28 (PB15)
/USB_D+: J2.3 (D+), R20.1
/USB_D-: J2.2 (D-), R21.1, R22.2
GND: C1.2, C2.2, C3.2, C4.2, C5.2, C6.2, C7.2, C8.2, C9.1, J1.1, J2.4 (GND), J2.5 (Shield), J3.4, Q1.2 (S), Q2.2 (S), Q3.2 (S), R2.2, R4.2, R6.2, SW10.1, U1.8 (VSSA), U1.23 (VSS), U1.35 (VSS), U1.47 (VSS); also elsewhere on the board
unnamed: C1.1, U1.5 (PD0), Y1.1
unnamed: C2.1, U1.6 (PD1), Y1.2
unnamed: F1.2, J2.1 (VBUS)
unnamed: Q1.1 (G), R1.2, R2.1
unnamed: Q2.1 (G), R3.2, R4.1
unnamed: Q3.1 (G), R5.2, R6.1
unnamed: TP1.1, U1.22 (PB11)
unnamed: TP2.1, U1.7 (NRST)
unnamed: TP3.1, U1.44 (BOOT0)
unnamed: TP4.1, U1.2 (PC13)
unnamed: TP5.1, U1.3 (PC14)
unnamed: TP6.1, U1.4 (PC15)
unnamed: TP7.1, U1.18 (PB0)
unnamed: TP8.1, U1.19 (PB1)
unnamed: TP9.1, U1.20 (PB2)
unnamed: TP10.1, U1.38 (PA15)
unnamed: TP11.1, U1.31 (PA10)

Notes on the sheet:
voeg oled scherm toe
XKB Enterprise TS-1187A-B-A-B
mechanical switch

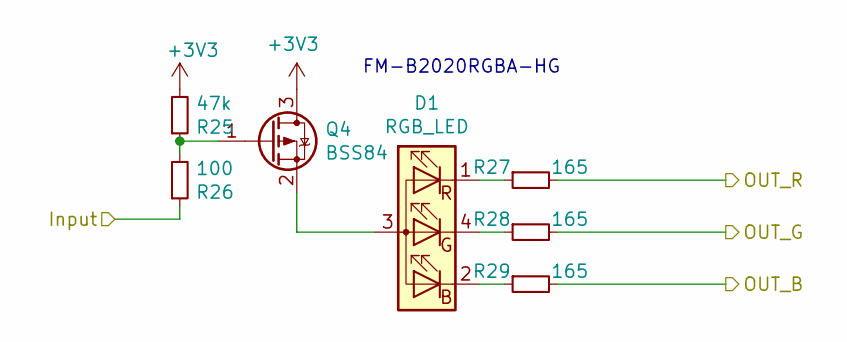
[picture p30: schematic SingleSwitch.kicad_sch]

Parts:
D1: RGB_LED; 2020_RGB
Q4: BSS84; SOT-23
R25: 47k; R_0603_1608Metric
R26: 100; R_0603_1608Metric
R27, R28, R29: 165; R_0603_1608Metric

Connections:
+3V3: Q4.3 (D), R25.2; also elsewhere on the board
/BlueChannel: R29.2; also elsewhere on the board
/C0R0: R26.1; also elsewhere on the board
/GreenChannel: R28.2; also elsewhere on the board
/RedChannel: R27.2; also elsewhere on the board
unnamed: D1.1 (RK), R27.1
unnamed: D1.2 (BK), R29.1
unnamed: D1.3 (A), Q4.2 (S)
unnamed: D1.4 (GK), R28.1
unnamed: Q4.1 (G), R25.1, R26.2

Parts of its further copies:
D2, D3, D4, D5, D6, D7, D8, D9, D10: RGB_LED; 2020_RGB
Q5, Q6, Q7, Q8, Q9, Q10, Q11, Q12, Q13: BSS84; SOT-23
R30, R35, R40, R45, R50, R55, R60, R65, R70: 47k; R_0603_1608Metric
R31, R36, R41, R46, R51, R56, R61, R66, R71: 100; R_0603_1608Metric
R32, R33, R34, R37, R38, R39, R42, R43, R44, R47, R48, R49, R52, R53, R54, R57, R58, R59, R62, R63, R64, R67, R68, R69, R72, R73, R74: 165; R_0603_1608Metric

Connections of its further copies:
+3V3: Q5.3 (D), Q6.3 (D), Q7.3 (D), Q8.3 (D), Q9.3 (D), Q10.3 (D), Q11.3 (D), Q12.3 (D), Q13.3 (D), R30.2, R35.2, R40.2, R45.2, R50.2, R55.2, R60.2, R65.2, R70.2; also elsewhere on the board
/BlueChannel: R34.2, R39.2, R44.2, R49.2, R54.2, R59.2, R64.2, R69.2, R74.2; also elsewhere on the board
/C0R1: R31.1; also elsewhere on the board
/C0R2: R36.1; also elsewhere on the board
/C1R0: R56.1; also elsewhere on the board
/C1R1: R61.1; also elsewhere on the board
/C1R2: R66.1; also elsewhere on the board
/C2R0: R41.1; also elsewhere on the board
/C2R1: R46.1; also elsewhere on the board
/C2R2: R51.1; also elsewhere on the board
/CtrlLed: R71.1; also elsewhere on the board
/GreenChannel: R33.2, R38.2, R43.2, R48.2, R53.2, R58.2, R63.2, R68.2, R73.2; also elsewhere on the board
/RedChannel: R32.2, R37.2, R42.2, R47.2, R52.2, R57.2, R62.2, R67.2, R72.2; also elsewhere on the board
unnamed: D2.1 (RK), R32.1
unnamed: D2.2 (BK), R34.1
unnamed: D2.3 (A), Q5.2 (S)
unnamed: D2.4 (GK), R33.1
unnamed: D3.1 (RK), R37.1
unnamed: D3.2 (BK), R39.1
unnamed: D3.3 (A), Q6.2 (S)
unnamed: D3.4 (GK), R38.1
unnamed: D4.1 (RK), R42.1
unnamed: D4.2 (BK), R44.1
unnamed: D4.3 (A), Q7.2 (S)
unnamed: D4.4 (GK), R43.1
unnamed: D5.1 (RK), R47.1
unnamed: D5.2 (BK), R49.1
unnamed: D5.3 (A), Q8.2 (S)
unnamed: D5.4 (GK), R48.1
unnamed: D6.1 (RK), R52.1
unnamed: D6.2 (BK), R54.1
unnamed: D6.3 (A), Q9.2 (S)
unnamed: D6.4 (GK), R53.1
unnamed: D7.1 (RK), R57.1
unnamed: D7.2 (BK), R59.1
unnamed: D7.3 (A), Q10.2 (S)
unnamed: D7.4 (GK), R58.1
unnamed: D8.1 (RK), R62.1
unnamed: D8.2 (BK), R64.1
unnamed: D8.3 (A), Q11.2 (S)
unnamed: D8.4 (GK), R63.1
unnamed: D9.1 (RK), R67.1
unnamed: D9.2 (BK), R69.1
unnamed: D9.3 (A), Q12.2 (S)
unnamed: D9.4 (GK), R68.1
unnamed: D10.1 (RK), R72.1
unnamed: D10.2 (BK), R74.1
unnamed: D10.3 (A), Q13.2 (S)
unnamed: D10.4 (GK), R73.1
unnamed: Q5.1 (G), R30.1, R31.2
unnamed: Q6.1 (G), R35.1, R36.2
unnamed: Q7.1 (G), R40.1, R41.2
unnamed: Q8.1 (G), R45.1, R46.2
unnamed: Q9.1 (G), R50.1, R51.2
unnamed: Q10.1 (G), R55.1, R56.2
unnamed: Q11.1 (G), R60.1, R61.2
unnamed: Q12.1 (G), R65.1, R66.2
unnamed: Q13.1 (G), R70.1, R71.2

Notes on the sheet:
FM-B2020RGBA-HG

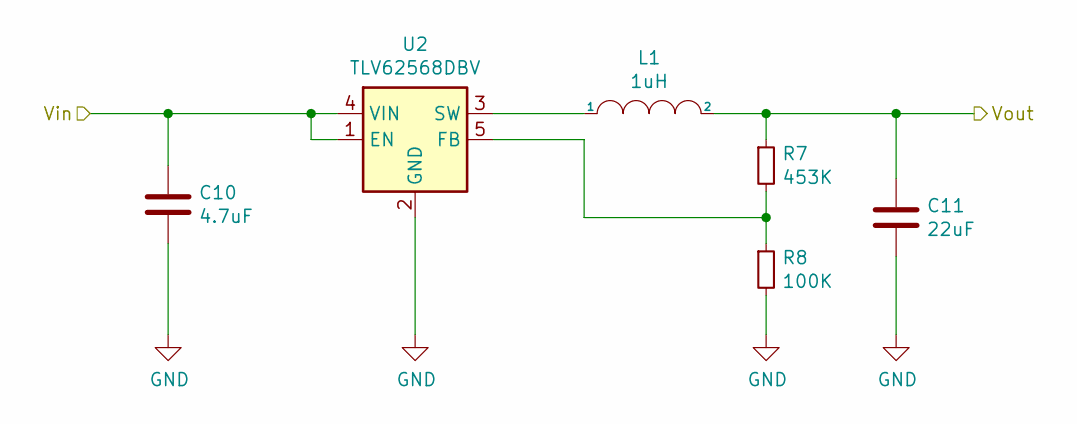
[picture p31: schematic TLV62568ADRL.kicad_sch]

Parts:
C10: 4.7uF; C_1206_3216Metric
C11: 22uF; C_0805_2012Metric
L1: 1uH; SRN3012TA-1R0Y
R7: 453K; R_0603_1608Metric
R8: 100K; R_0603_1608Metric
U2: TLV62568DBV; SOT-23-5

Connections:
+3V3: C11.1, L1.2, R7.1; also elsewhere on the board
+5V: C10.1, U2.1 (EN), U2.4 (VIN); also elsewhere on the board
GND: C10.2, C11.2, R8.2, U2.2 (GND); also elsewhere on the board
unnamed: L1.1, U2.3 (SW)
unnamed: R7.2, R8.1, U2.5 (FB)

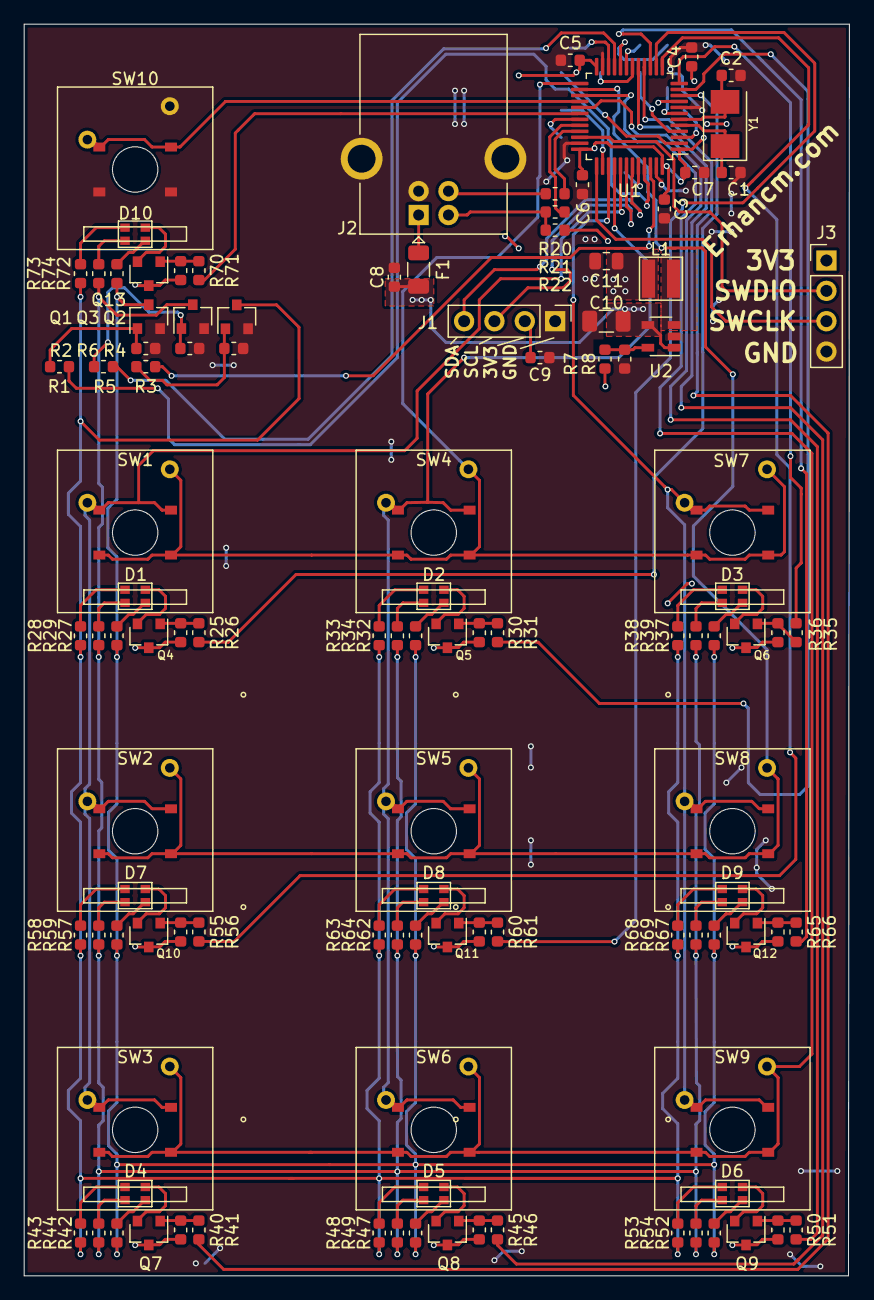
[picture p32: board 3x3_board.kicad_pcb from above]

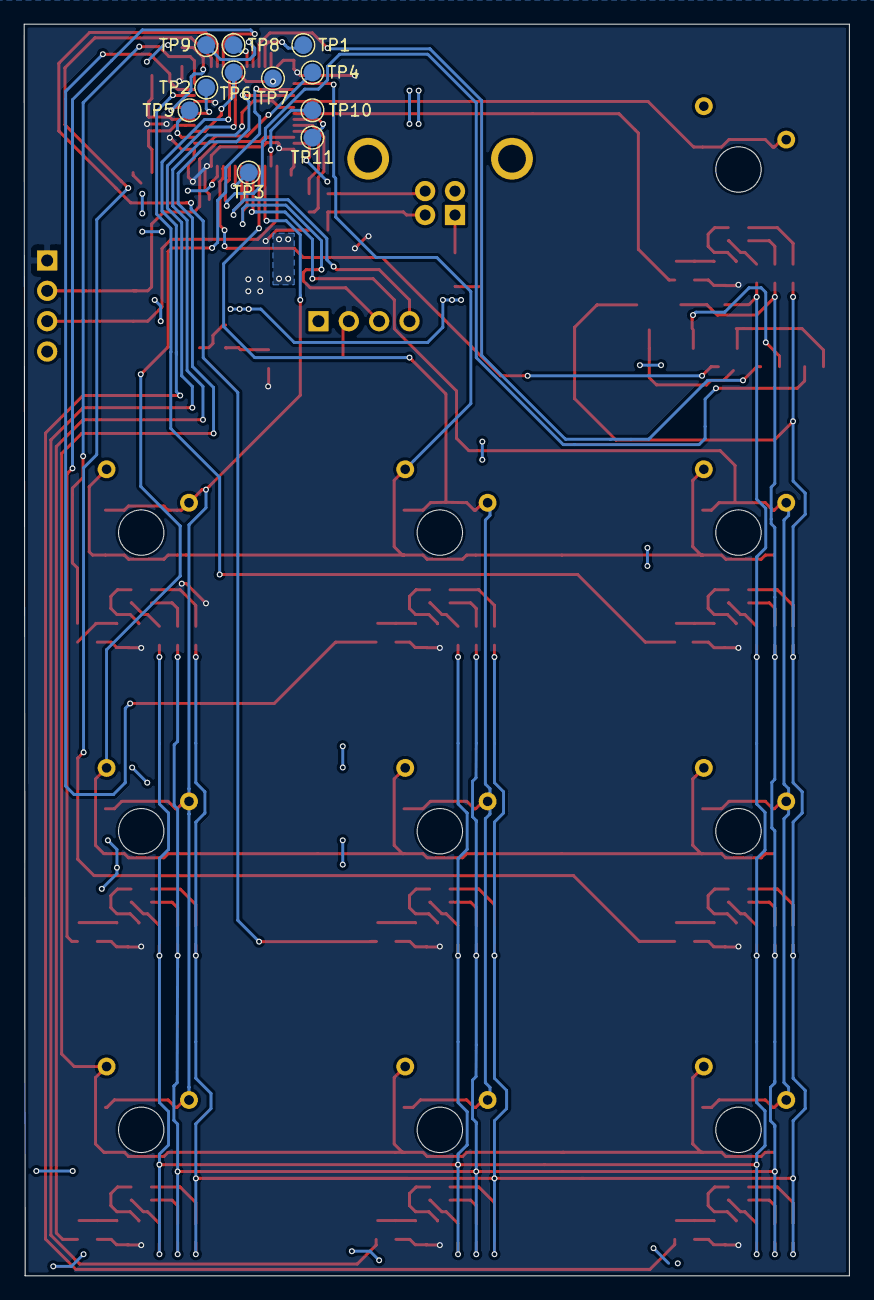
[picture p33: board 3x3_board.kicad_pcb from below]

Board: 2 copper layers, 69.1 x 104.8 mm, 124 parts (11 on the bottom side), 103 nets.

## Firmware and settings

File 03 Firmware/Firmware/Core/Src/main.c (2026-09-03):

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
/* Includes ------------------------------------------------------------------*/
#include "main.h"
#include "i2c.h"
#include "usb_device.h"
#include "gpio.h"

/* USER CODE BEGIN Includes */
#include "keypad.h"
#include "storage.h"
#include "hid_reports.h"
#include "macro.h"
#include "led_mux.h"
#include "ui.h"
#include "clock.h"
/* USER CODE END Includes */


void SystemClock_Config(void);
/**
  * @brief  The application entry point.
  * @retval int
  */
int main(void)
{

  /* USER CODE BEGIN 1 */
  /* Bootloader jump_app() leaves PRIMASK set. SysTick/USB/TIM2 never run
   * until this, and ssd1306_Init()'s HAL_Delay(80) would hang forever. */
  SCB->VTOR = 0x08001000U;
  __enable_irq();
  /* USER CODE END 1 */

  /* MCU Configuration--------------------------------------------------------*/

  /* Reset of all peripherals, Initializes the Flash interface and the Systick. */
  HAL_Init();

  /* Configure the system clock */
  SystemClock_Config();

  /* Initialize all configured peripherals */
  MX_GPIO_Init();
  MX_I2C1_Init();
  MX_USB_DEVICE_Init();
  /* USER CODE BEGIN 2 */
  keypad_init();
  storage_init();
  clock_init();
  hid_init();
  led_mux_init();
  macro_init();
  ui_init();
  /* USER CODE END 2 */

  /* Infinite loop */
      while (1)
  {
  /* USER CODE BEGIN WHILE */
    static uint32_t last_ms;
    static uint8_t tick_synced;
    uint32_t now = HAL_GetTick();
    if (!tick_synced) {
      last_ms = now;
      tick_synced = 1;
    }
    uint16_t steps = 0;
    while (last_ms != now) {
      last_ms++;
      ui_tick();
      if (steps < 1000) {
        steps++;
      }
      now = HAL_GetTick();
    }
    if (steps) {
      hid_tick();
      macro_tick(steps);
    }
    if ((hid_key_evt_pending() || macro_busy()) && hid_configured()) {
      /* Clock/OLED I2C is ~25 ms blocking; don't pace HID behind it. */
      if (hid_in_ready()) {
        if (hid_key_evt_pending()) {
          hid_tick();
        } else {
          macro_tick(0);
        }
      }
    } else {
      ui_draw_if_needed();
    }
    /* USER CODE END WHILE */

    /* USER CODE BEGIN 3 */
  }
  /* USER CODE END 3 */
}

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


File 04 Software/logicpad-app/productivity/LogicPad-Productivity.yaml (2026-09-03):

# LogicPad setup pack (logicpadPack: 1)
logicpadPack: 1
exportedAt: 2026-08-31T08:08:37.800Z
profiles:
  - name: Office
    lightMode: 1
    bright: 7
    dim: 3
    keys:
      - index: 0
        label: Copy
        led: 4
        acts:
          - type: 1
            mods: 1
            code: 6
        text: ""
      - index: 1
        label: Paste
        led: 3
        acts:
          - type: 1
            mods: 1
            code: 25
        text: ""
      - index: 2
        label: Save
        led: 1
        acts:
          - type: 1
            mods: 1
            code: 22
        text: ""
      - index: 3
        label: Undo
        led: 2
        acts:
          - type: 1
            mods: 1
            code: 29
        text: ""
      - index: 4
        label: Bold
        led: 1
        acts:
          - type: 1
            mods: 2
            code: 5
        text: ""
      - index: 5
        label: Find
        led: 4
        acts:
          - type: 1
            mods: 1
            code: 9
        text: ""
      - index: 6
        label: Print
        led: 0
        acts:
          - type: 1
            mods: 1
            code: 19
        text: ""
      - index: 7
        label: Close
        led: 0
        acts:
          - type: 1
            mods: 1
            code: 26
        text: ""
      - index: 8
        label: Note
        led: 1
        acts:
          - type: 8
            mods: 0
            code: 0
        text: |
          Notes:
        launches: []
  - name: Files
    lightMode: 2
    bright: 6
    dim: 2
    keys:
      - index: 0
        label: Copy
        led: 4
        acts:
          - type: 1
            mods: 1
            code: 6
        text: ""
      - index: 1
        label: Paste
        led: 3
        acts:
          - type: 1
            mods: 1
            code: 25
        text: ""
      - index: 2
        label: Ren
        led: 1
        acts:
          - type: 1
            mods: 1
            code: 21
        text: ""
      - index: 3
        label: Del
        led: 2
        acts:
          - type: 1
            mods: 0
            code: 76
        text: ""
      - index: 4
        label: New
        led: 1
        acts:
          - type: 1
            mods: 4
            code: 17
        text: ""
      - index: 5
        label: Up
        led: 0
        acts:
          - type: 1
            mods: 1
            code: 82
        text: ""
      - index: 6
        label: Sel
        led: 4
        acts:
          - type: 1
            mods: 1
            code: 4
        text: ""
      - index: 7
        label: Path
        led: 1
        acts:
          - type: 8
            mods: 0
            code: 0
        text: |
          C:\Users\
      - index: 8
        label: Exp
        led: 0
        acts: []
        text: ""
        launches:
          - path: explorer.exe
            args: ""
            slot: 0
  - name: Browse
    lightMode: 3
    bright: 7
    dim: 3
    keys:
      - index: 0
        label: Tab
        led: 1
        acts:
          - type: 1
            mods: 1
            code: 4
        text: ""
      - index: 1
        label: Reload
        led: 4
        acts:
          - type: 1
            mods: 1
            code: 21
        text: ""
      - index: 2
        label: Back
        led: 4
        acts:
          - type: 1
            mods: 1
            code: 80
        text: ""
      - index: 3
        label: Fwd
        led: 4
        acts:
          - type: 1
            mods: 1
            code: 79
        text: ""
      - index: 4
        label: Find
        led: 2
        acts:
          - type: 1
            mods: 1
            code: 9
        text: ""
      - index: 5
        label: Home
        led: 3
        acts:
          - type: 1
            mods: 1
            code: 14
        text: ""
      - index: 6
        label: Full
        led: 0
        acts:
          - type: 1
            mods: 0
            code: 67
        text: ""
      - index: 7
        label: Close
        led: 0
        acts:
          - type: 1
            mods: 1
            code: 26
        text: ""
      - index: 8
        label: URL
        led: 1
        acts:
          - type: 8
            mods: 0
            code: 0
        text: |
          https://
        launches: []
  - name: CAD
    lightMode: 5
    bright: 8
    dim: 2
    keys:
      - index: 0
        label: Save
        led: 1
        acts:
          - type: 1
            mods: 1
            code: 22
        text: ""
      - index: 1
        label: Undo
        led: 2
        acts:
          - type: 1
            mods: 1
            code: 29
        text: ""
      - index: 2
        label: Fit
        led: 4
        acts:
          - type: 1
            mods: 0
            code: 15
        text: ""
      - index: 3
        label: Build
        led: 1
        acts:
          - type: 1
            mods: 1
            code: 5
        text: ""
      - index: 4
        label: Front
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

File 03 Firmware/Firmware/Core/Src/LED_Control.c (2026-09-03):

#include "LED_Control.h"
#include "gpio.h" // Assuming GPIO_PIN_x and HAL_GPIO_WritePin are defined here

// Define LED pins based on PIN_CONFIGURATION.md
// Anode pins (CxRy_Pin) are on GPIOA
#define C0R0_GPIO_Port GPIOA
#define C0R0_Pin GPIO_PIN_0
#define C0R1_GPIO_Port GPIOA
#define C0R1_Pin GPIO_PIN_1
#define C0R2_GPIO_Port GPIOA
#define C0R2_Pin GPIO_PIN_2
#define C1R0_GPIO_Port GPIOA
#define C1R0_Pin GPIO_PIN_3
#define C1R1_GPIO_Port GPIOA
#define C1R1_Pin GPIO_PIN_4
#define C1R2_GPIO_Port GPIOA
#define C1R2_Pin GPIO_PIN_5
#define C2R0_GPIO_Port GPIOA
#define C2R0_Pin GPIO_PIN_6
#define C2R1_GPIO_Port GPIOA
#define C2R1_Pin GPIO_PIN_7
#define C2R2_GPIO_Port GPIOA
#define C2R2_Pin GPIO_PIN_8

// Cathode control pins (R_Ctrl_Pin, G_Ctrl_Pin, B_Ctrl_Pin) are on GPIOB
#define B_Ctrl_GPIO_Port GPIOB
#define B_Ctrl_Pin GPIO_PIN_10
#define R_Ctrl_GPIO_Port GPIOB
#define R_Ctrl_Pin GPIO_PIN_8
#define G_Ctrl_GPIO_Port GPIOB
#define G_Ctrl_Pin GPIO_PIN_9

// Array of anode pins for easier iteration
GPIO_TypeDef* Anode_Ports[] = {C0R0_GPIO_Port, C0R1_GPIO_Port, C0R2_GPIO_Port,
                               C1R0_GPIO_Port, C1R1_GPIO_Port, C1R2_GPIO_Port,
                               C2R0_GPIO_Port, C2R1_GPIO_Port, C2R2_GPIO_Port,
                               CtrlLed_GPIO_Port};
uint16_t Anode_Pins[] = {C0R0_Pin, C0R1_Pin, C0R2_Pin,
                         C1R0_Pin, C1R1_Pin, C1R2_Pin,
                         C2R0_Pin, C2R1_Pin, C2R2_Pin,
                         CtrlLed_Pin};
#define NUM_ANODE_PINS (sizeof(Anode_Pins) / sizeof(Anode_Pins[0]))

// Function to turn all LEDs of a specific color ON or OFF
void Set_All_Color_LEDs(GPIO_TypeDef* R_Port, uint16_t R_Pin,
                        GPIO_TypeDef* G_Port, uint16_t G_Pin,
                        GPIO_TypeDef* B_Port, uint16_t B_Pin,
                        GPIO_PinState R_state, GPIO_PinState G_state, GPIO_PinState B_state)
{  
    // Set all anode pins high to enable all LEDs
    for (int i = 0; i < NUM_ANODE_PINS; i++)
    {
        HAL_GPIO_WritePin(Anode_Ports[i], Anode_Pins[i], GPIO_PIN_RESET);
    }
    // Set the cathode control pins to the desired states
    // Set all anode pins high to enable all LEDs
    for (int i = 0; i < NUM_ANODE_PINS; i++)
    {
        HAL_GPIO_WritePin(Anode_Ports[i], Anode_Pins[i], GPIO_PIN_RESET);
    }
    // Set the cathode control pins to the desired states
    HAL_GPIO_WritePin(R_Port, R_Pin, R_state);
    HAL_GPIO_WritePin(G_Port, G_Pin, G_state);
    HAL_GPIO_WritePin(B_Port, B_Pin, B_state);
}

// Function to turn a specific LED ON or OFF
void Set_Individual_LED(GPIO_TypeDef* Anode_Port, uint16_t Anode_Pin,
                        GPIO_TypeDef* Ctrl_Port, uint16_t Ctrl_Pin, GPIO_PinState state)
{
    // Turn off all other LEDs first
    for (int i = 0; i < NUM_ANODE_PINS; i++)
    {
        HAL_GPIO_WritePin(Anode_Ports[i], Anode_Pins[i], GPIO_PIN_RESET);
    }
    HAL_GPIO_WritePin(R_Ctrl_GPIO_Port, R_Ctrl_Pin, GPIO_PIN_SET);
    HAL_GPIO_WritePin(G_Ctrl_GPIO_Port, G_Ctrl_Pin, GPIO_PIN_SET);
    HAL_GPIO_WritePin(B_Ctrl_GPIO_Port, B_Ctrl_Pin, GPIO_PIN_SET);

    // Set the specific anode pin
    HAL_GPIO_WritePin(Anode_Port, Anode_Pin, state);
    // Set the specific cathode control pin
    HAL_GPIO_WritePin(Ctrl_Port, Ctrl_Pin, (state == GPIO_PIN_SET) ? GPIO_PIN_RESET : GPIO_PIN_SET);
}


void LED_Test_All(void)
{
    // Turn all Red LEDs on
    Set_All_Color_LEDs(R_Ctrl_GPIO_Port, R_Ctrl_Pin, G_Ctrl_GPIO_Port, G_Ctrl_Pin, B_Ctrl_GPIO_Port, B_Ctrl_Pin,
                       GPIO_PIN_SET, GPIO_PIN_RESET, GPIO_PIN_RESET);
    HAL_Delay(1000); // Display Red for 1 second

    // Turn all Green LEDs on
    Set_All_Color_LEDs(R_Ctrl_GPIO_Port, R_Ctrl_Pin, G_Ctrl_GPIO_Port, G_Ctrl_Pin, B_Ctrl_GPIO_Port, B_Ctrl_Pin,
                       GPIO_PIN_RESET, GPIO_PIN_SET, GPIO_PIN_RESET);
    HAL_Delay(1000); // Display Green for 1 second

    // Turn all Blue LEDs on
    Set_All_Color_LEDs(R_Ctrl_GPIO_Port, R_Ctrl_Pin, G_Ctrl_GPIO_Port, G_Ctrl_Pin, B_Ctrl_GPIO_Port, B_Ctrl_Pin,
                       GPIO_PIN_RESET, GPIO_PIN_RESET, GPIO_PIN_SET);
    HAL_Delay(1000); // Display Blue for 1 second

    // Turn all LEDs off
    Set_All_Color_LEDs(R_Ctrl_GPIO_Port, R_Ctrl_Pin, G_Ctrl_GPIO_Port, G_Ctrl_Pin, B_Ctrl_GPIO_Port, B_Ctrl_Pin,
                       GPIO_PIN_RESET, GPIO_PIN_RESET, GPIO_PIN_RESET);
    HAL_Delay(1000); // Display nothing for 1 second
}

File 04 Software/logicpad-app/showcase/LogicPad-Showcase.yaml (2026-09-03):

# LogicPad setup pack (logicpadPack: 1)
logicpadPack: 1
exportedAt: 2026-08-28T16:41:07.585Z
profiles:
  - name: Create
    lightMode: 5
    bright: 8
    dim: 3
    keys:
      - index: 0
        label: Copy
        led: 4
        acts:
          - type: 1
            mods: 1
            code: 6
        text: ""
      - index: 1
        label: Paste
        led: 3
        acts:
          - type: 1
            mods: 1
            code: 25
        text: ""
      - index: 2
        label: Undo
        led: 2
        acts:
          - type: 1
            mods: 1
            code: 29
        text: ""
      - index: 3
        label: Save
        led: 1
        acts:
          - type: 1
            mods: 1
            code: 22
        text: ""
      - index: 4
        label: Find
        led: 4
        acts:
          - type: 1
            mods: 1
            code: 9
        text: ""
      - index: 5
        label: Run
        led: 1
        acts:
          - type: 1
            mods: 2
            code: 21
        text: ""
      - index: 6
        label: Term
        led: 2
        acts:
          - type: 1
            mods: 2
            code: 23
        text: ""
      - index: 7
        label: Close
        led: 0
        acts:
          - type: 1
            mods: 1
            code: 26
        text: ""
      - index: 8
        label: Snippet
        led: 1
        acts:
          - type: 8
            mods: 0
            code: 0
        text: |
          // LogicPad demo
        launches:
          - path: Cursor.exe
            args: ""
            slot: 0
  - name: Stream
    lightMode: 7
    bright: 9
    dim: 2
    keys:
      - index: 0
        label: Rec
        led: 2
        acts:
          - type: 1
            mods: 4
            code: 82
        text: ""
      - index: 1
        label: Mute
        led: 0
        acts:
          - type: 6
            mods: 0
            code: 226
        text: ""
      - index: 2
        label: Vol+
        led: 0
        acts:
          - type: 6
            mods: 0
            code: 233
        text: ""
      - index: 3
        label: Vol-
        led: 0
        acts:
          - type: 6
            mods: 0
            code: 234
        text: ""
      - index: 4
        label: Scene
        led: 3
        acts:
          - type: 1
            mods: 4
            code: 9
        text: ""
      - index: 5
        label: Mic
        led: 1
        acts:
          - type: 1
            mods: 4
            code: 16
        text: ""
      - index: 6
        label: Chat
        led: 4
        acts:
          - type: 1
            mods: 2
            code: 9
        text: ""
      - index: 7
        label: Click
        led: 0
        acts:
          - type: 3
            mods: 1
            code: 0
        text: ""
      - index: 8
        label: OBS
        led: 2
        acts: []
        text: ""
        launches:
          - path: obs64.exe
            args: ""
            slot: 0
  - name: Meet
    lightMode: 1
    bright: 6
    dim: 2
    keys:
      - index: 0
        label: Mute
        led: 2
        acts:
          - type: 6
            mods: 0
            code: 226
        text: ""
      - index: 1
        label: Cam
        led: 1
        acts:
          - type: 1
            mods: 4
            code: 57
        text: ""
      - index: 2
        label: Share
        led: 4
        acts:
          - type: 1
            mods: 4
            code: 19
        text: ""
      - index: 3
        label: Leave
        led: 2
        acts:
          - type: 1
            mods: 4
            code: 43
        text: ""
      - index: 4
        label: OK
        led: 1
        acts:
          - type: 1
            mods: 0
            code: 40
        text: ""
      - index: 5
        label: Up
        led: 0
        acts:
          - type: 1
            mods: 0
            code: 82
        text: ""
      - index: 6
        label: Down
        led: 0
        acts:
          - type: 1
            mods: 0
            code: 81
        text: ""
      - index: 7
        label: Hand
        led: 3
        acts:
          - type: 1
            mods: 4
            code: 35
        text: ""
      - index: 8
        label: Teams
        led: 1
        acts: []
        text: ""
        launches:
          - path: Teams.exe
            args: ""
            slot: 0
  - name: Browse
    lightMode: 3
    bright: 7
    dim: 3
    keys:
      - index: 0
        label: NewTab
        led: 1
        acts:
          - type: 1
            mods: 1
            code: 4
        text: ""
      - index: 1
        label: Close
        led: 0
        acts:
          - type: 1
            mods: 1
            code: 26
        text: ""
      - index: 2
        label: Back
        led: 4
        acts:
          - type: 1
            mods: 1
            code: 80
        text: ""
      - index: 3
        label: Fwd
        led: 4
        acts:
          - type: 1
            mods: 1
            code: 79
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

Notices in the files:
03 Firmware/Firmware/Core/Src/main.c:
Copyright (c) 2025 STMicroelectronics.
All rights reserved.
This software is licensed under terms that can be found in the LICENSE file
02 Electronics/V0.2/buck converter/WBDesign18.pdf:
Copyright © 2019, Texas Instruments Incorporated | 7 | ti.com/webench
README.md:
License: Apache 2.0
